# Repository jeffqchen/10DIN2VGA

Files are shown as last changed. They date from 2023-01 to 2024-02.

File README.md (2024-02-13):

# 10DIN2VGA Multi-Purpose Dongle for Sega Saturn

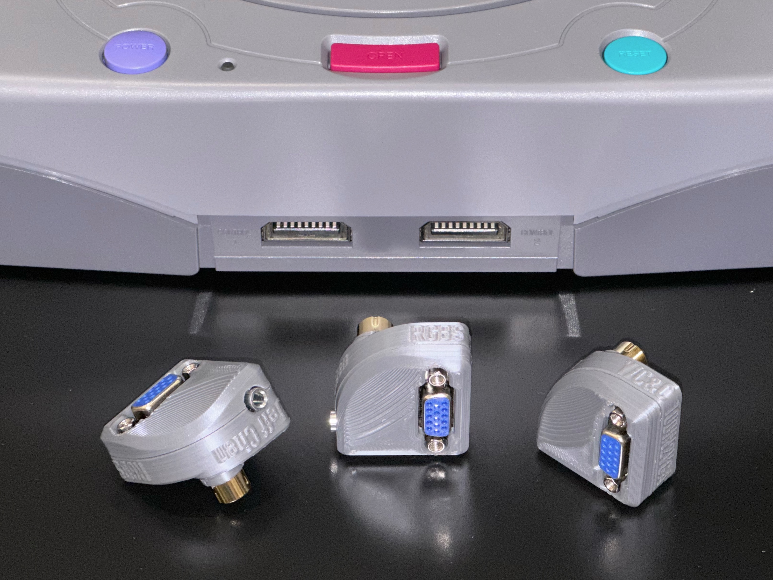
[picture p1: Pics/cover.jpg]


This is a 10-pin mini DIN to VGA dongle that supports outputting RGBS or S-video & composite video signal, plus stereo audio, from a Sega Saturn.

The RGBS signal is compatible with 75-ohm terminated SCART video.

The S-video & composite video signals are directly output from the console.

This dongle belongs to my endeavour of [Console VGA Dongles Series](https://github.com/jeffqchen/Console-VGA-Dongle-Series/blob/main/README.md).

## Functionality

You need to decide the configuration of this dongle during assembly, by closing corresponding jumpers on the PCBs.

Due to the incompatibilities between the two configurations and the possibility of causing damage by mixing up the dongle and adapter, I decided not to include switches inside the dongle, but instead solder jumpers and clear marking on the outer shell.

### RGBS Configuration

The RGBS mode is the primary objective of this project.

When configured to RGBS mode, you can opt to use C-Sync when using with an NTSC console, or use either Luma or composite video as sync for compatibility with PAL consoles.

### S-Video/Composite Video Adapter Configuration (Optional)

When configured to adapter mode, you can use the widely available and cheap VGA to S-Video/CVBS adapter from Amazon to output the aformentioned video format.

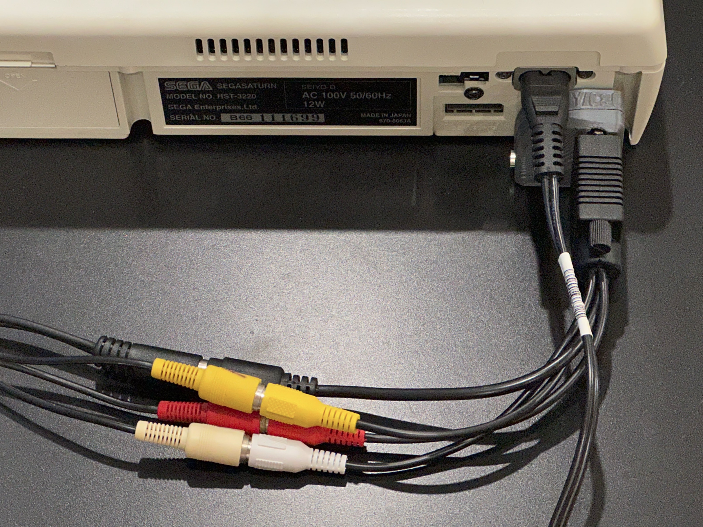
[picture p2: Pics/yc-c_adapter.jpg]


Make sure the pinout of your adapter is as the following diagram:

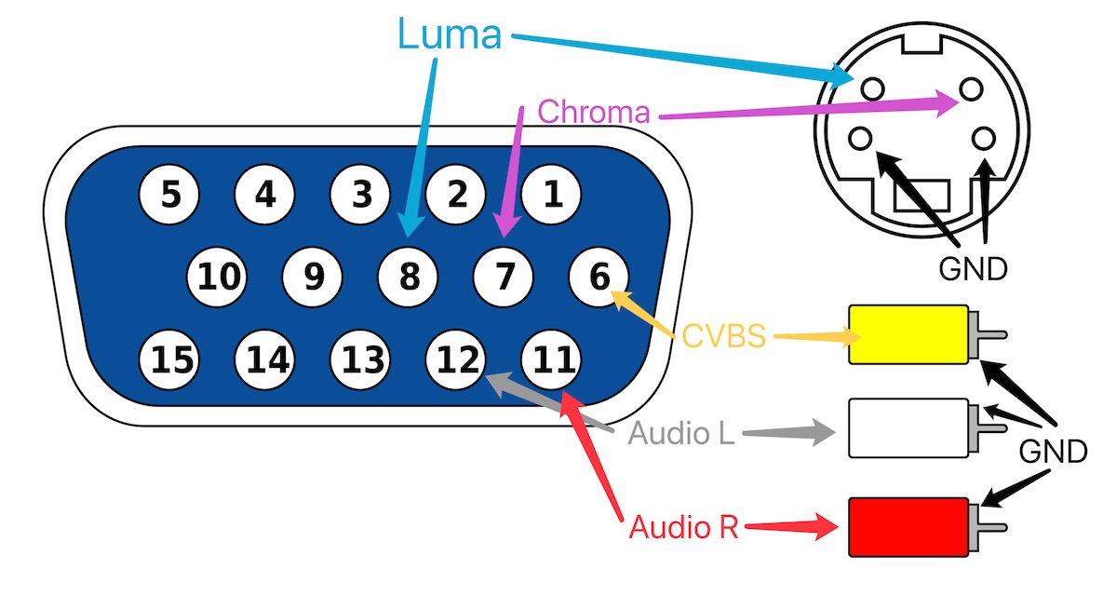
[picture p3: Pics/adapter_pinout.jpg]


*It is possible to modify the solder jumpers to change the adapter between the two configurations. However it's not recommended to repeatedly taking this dongle apart for that purpose, as the structural integrity might become compromised.*

## Design Details

The 10-pin mini DIN connector on the Sega Saturn has several problems.

The biggest one is that there is only one correct way to insert it, and infinite wrong ways to attempt. There is also no easy way to tell whether you are holding it correctly without triple checking with your eyes. It's also very difficult to maintain the correct orientation during insertion, even after you've confirmed it.

Most 10-pin DIN ports on the Saturn are badly damaged due to bad attempts to insert a video cable. Combined with too much force applied, the connector is frequently broken.

Due to the position of the port, the strain from the video cable will stress the connector and make the connection unreliable, or even reduce the life of the port and/or the cable.

The design of this dongle eliminates all the aforementioned problems.

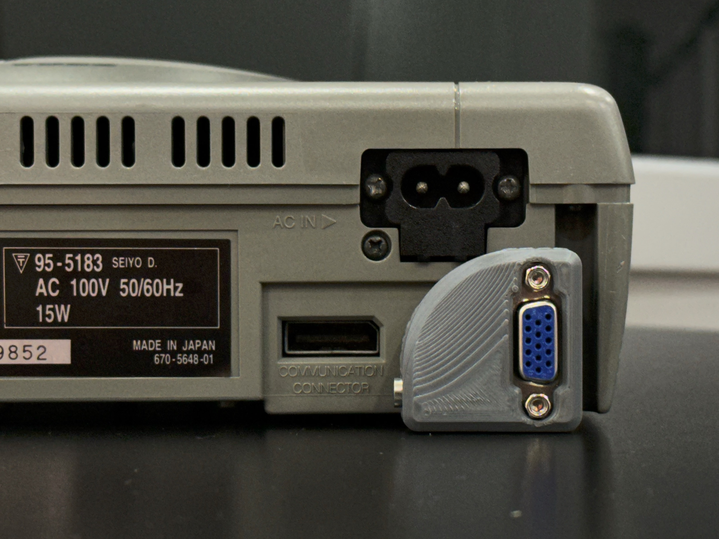
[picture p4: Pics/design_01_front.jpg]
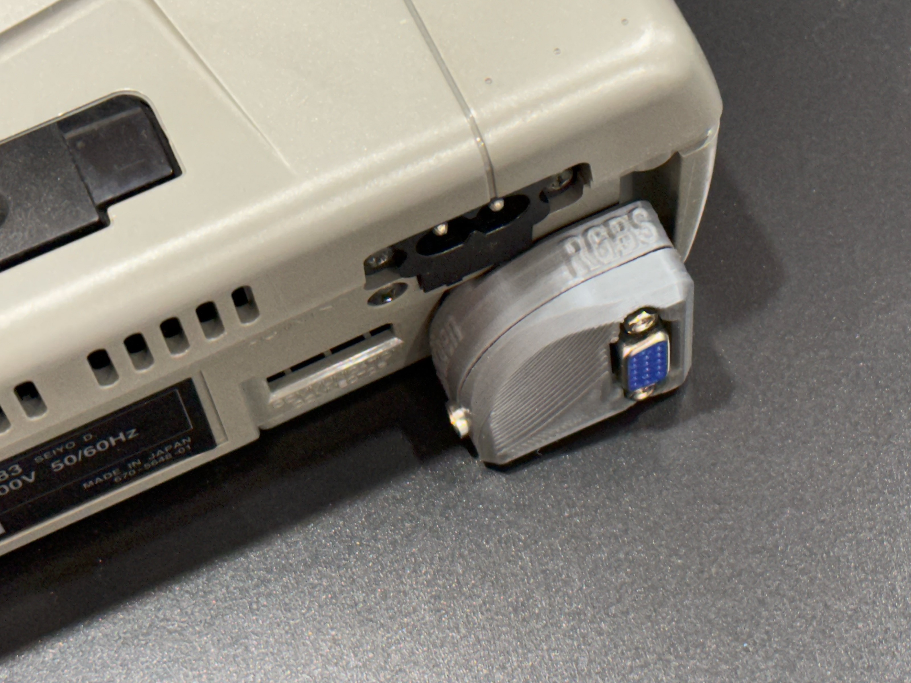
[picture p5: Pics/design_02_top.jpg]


The shape of the outside shell makes it easy to tell which way it's facing. Make sure the curve is in the 2nd quadrant and you know it's the correct way.

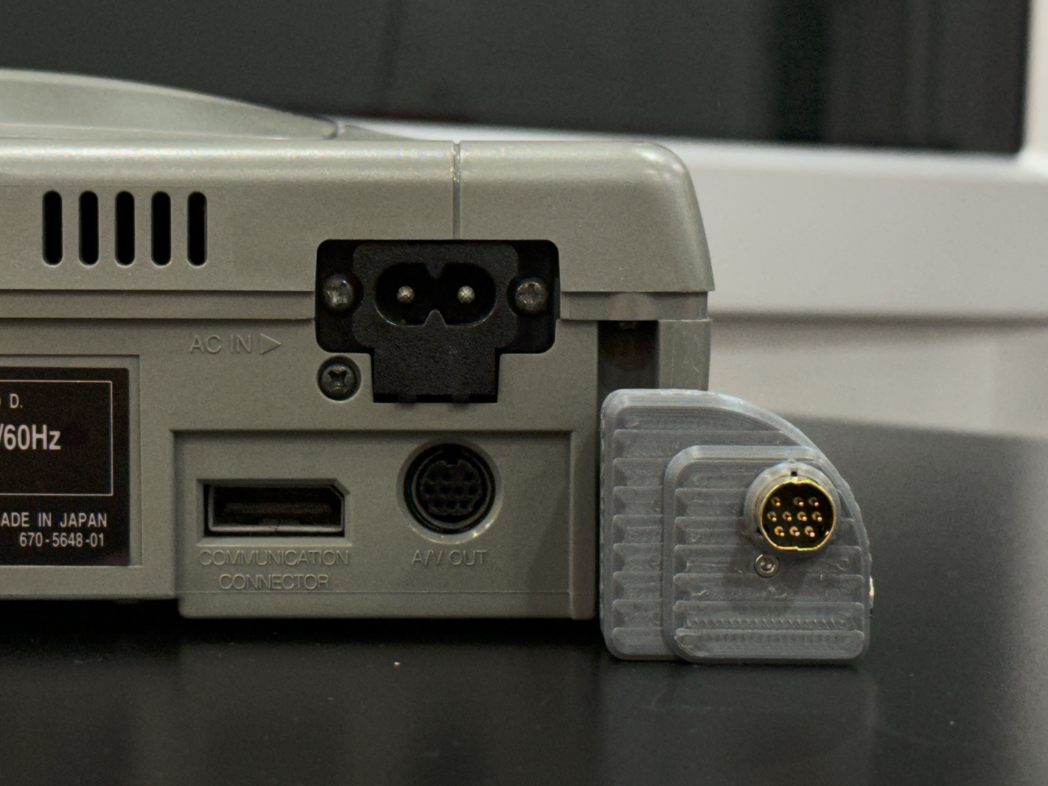
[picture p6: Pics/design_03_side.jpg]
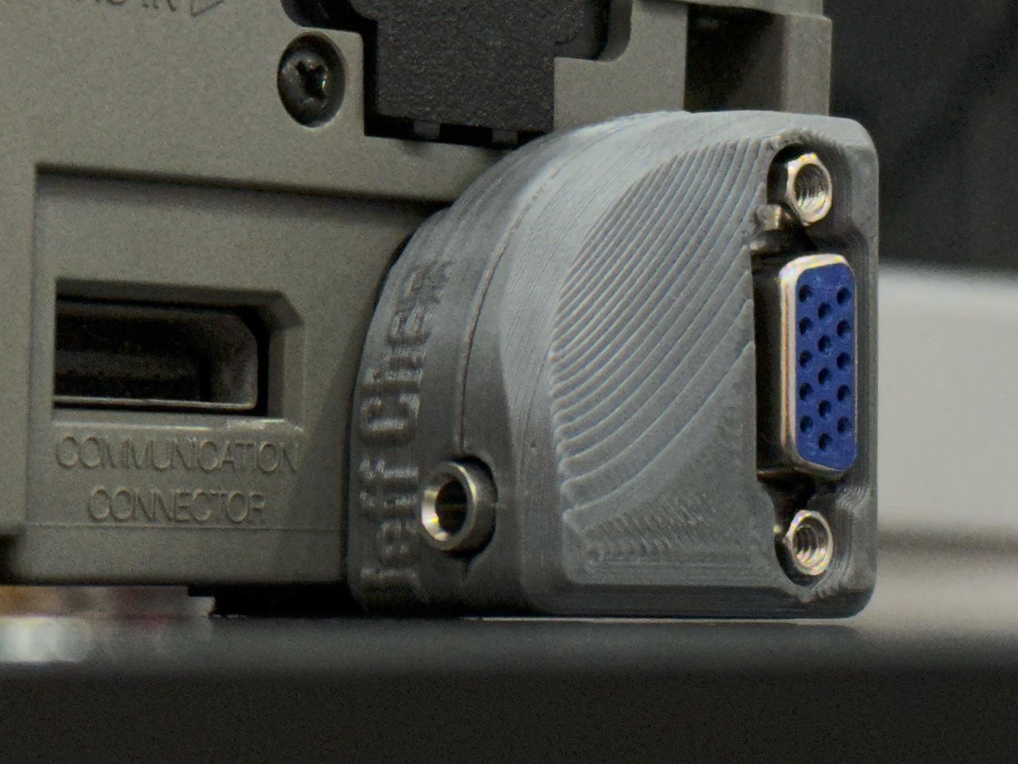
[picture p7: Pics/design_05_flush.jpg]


The shape of the inside shell conforms to the indented area around the AV port on the console, with the bottom of the dongle flat and flush with the table. This will ensure there is only one way to plug in the adapter. Since the adapter tightly follows the outline of the shell, rotational stress and downward stress are effectively offloaded to the shell of the console, as well as making it impossible to insert the connector too far into the console.

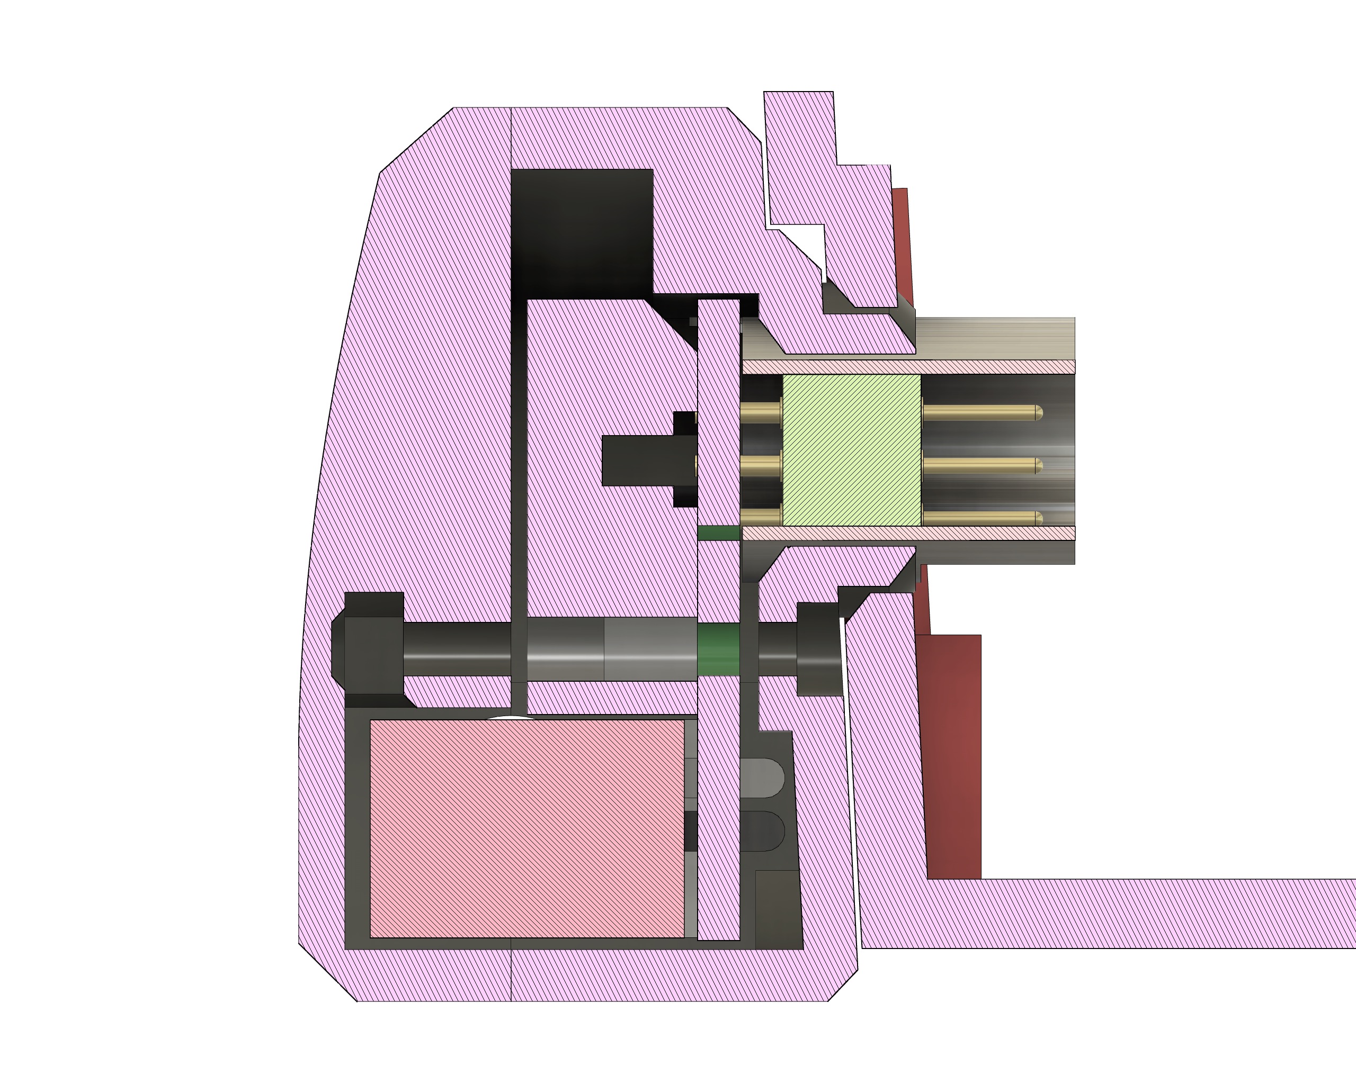
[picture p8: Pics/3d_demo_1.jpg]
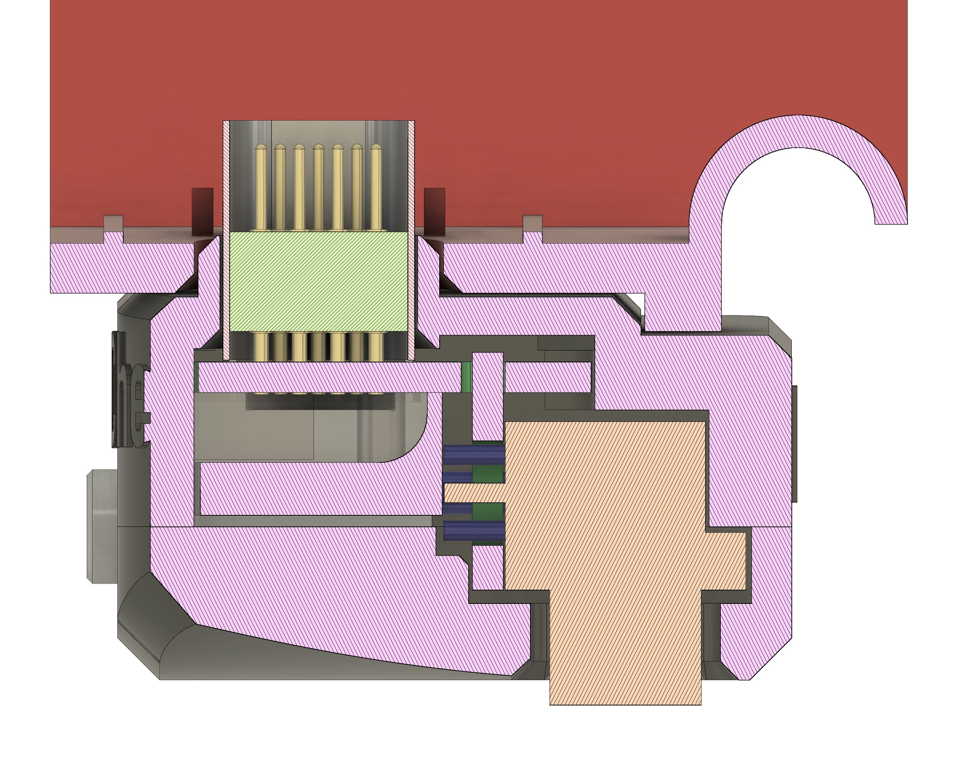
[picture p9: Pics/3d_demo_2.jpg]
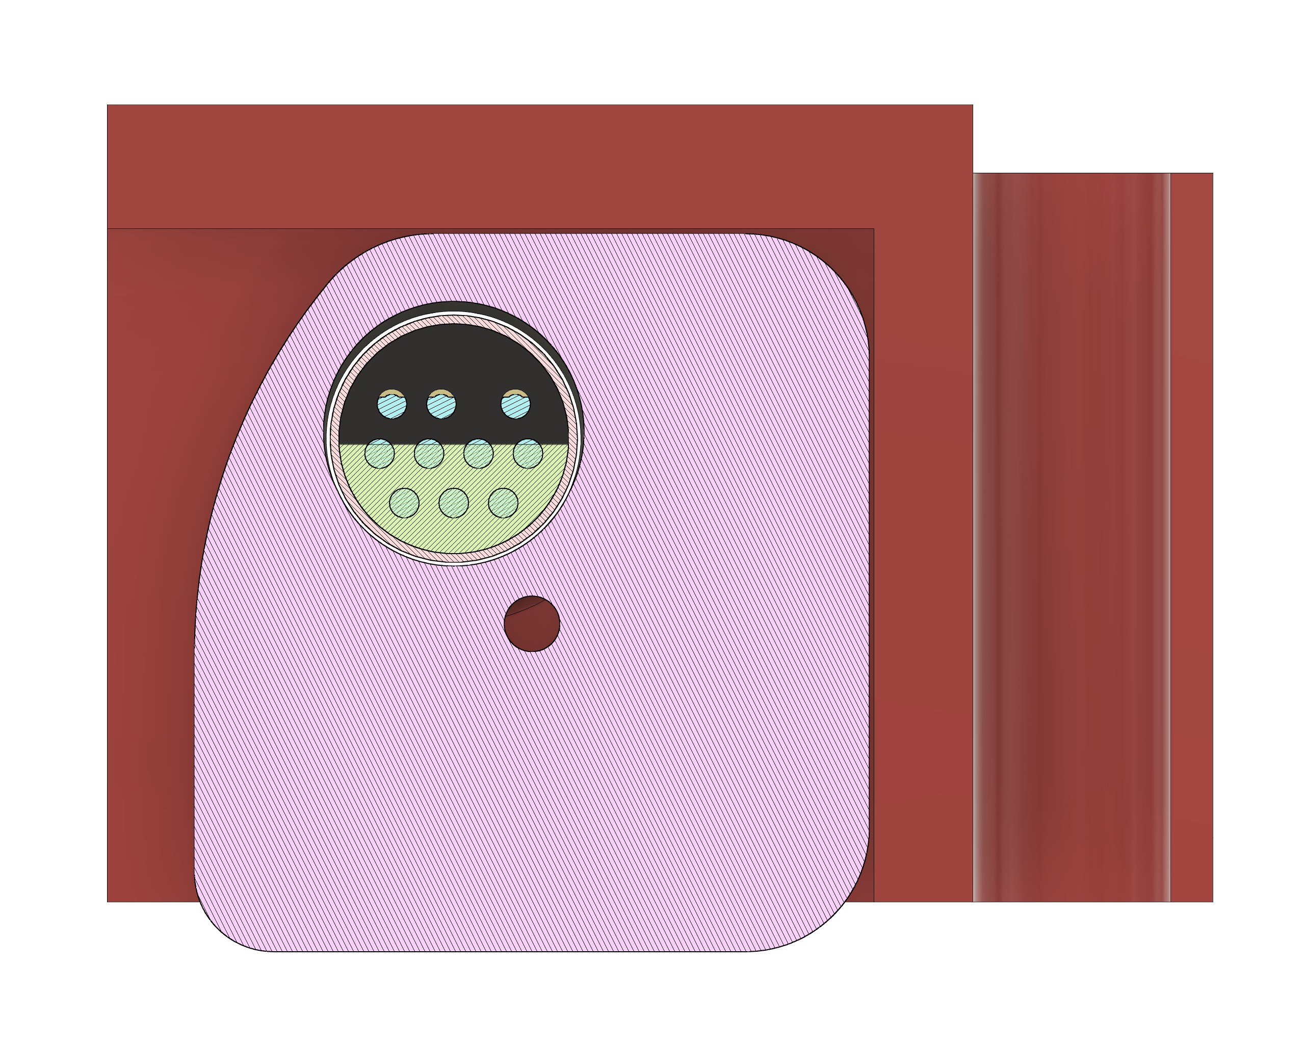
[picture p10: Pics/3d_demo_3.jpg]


The VGA port stands vertically, which ensures that it's strong against downward stress itself, as well as avoiding a rotationally pulling tendency that could pull the 10-pin DIN connector out of the console.

The optional 3.5mm audio jack was carefully positioned so that it doesn't block the communication port.

The power jack was also avoided, including the launch version with a slightly protruding profile.

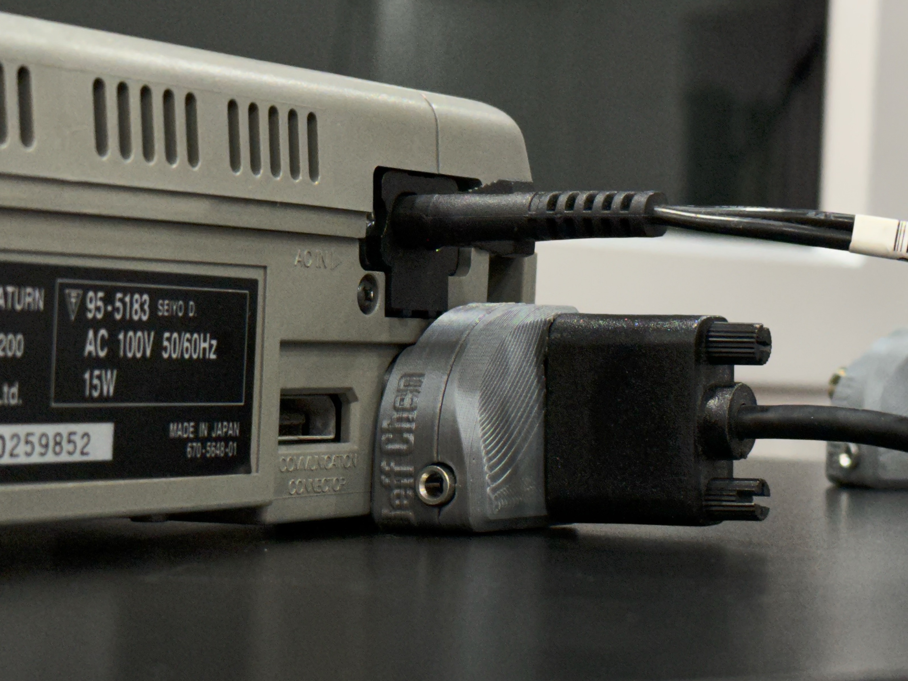
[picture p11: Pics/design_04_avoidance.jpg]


## Parts

- Project PCB
  - [Main Board](https://oshpark.com/projects/ftX4cA6v)
  - [VGA Board](https://oshpark.com/projects/xInxeNXi)
  
- 3D Printed Shell
  - [Front Shell (Universal)](https://github.com/jeffqchen/10DIN2VGA/blob/main/3D%20Print/Shell%20Front.stl)
  - Back Shell (Choose one according to your configuration)
    - [RGBS Marking](https://github.com/jeffqchen/10DIN2VGA/blob/main/3D%20Print/Shell%20Back-RGB.stl)
    - [Y/C & C Marking](https://github.com/jeffqchen/10DIN2VGA/blob/main/3D%20Print/Shell%20Back-YC.stl)
    - [No Marking](https://github.com/jeffqchen/10DIN2VGA/blob/main/3D%20Print/Shell%20Back.stl)
  - [Insert](https://github.com/jeffqchen/10DIN2VGA/blob/main/3D%20Print/Insert.stl)

- VGA Port Slim, Female - [Link](https://github.com/jeffqchen/JeffParts/blob/main/Connectors/HD15/Slim/Female%20PCB/info.md)

- 10 pin Mini DIN Male Plug, Through-Hole Type - [Link](https://github.com/jeffqchen/JeffParts/blob/main/Connectors/Mini%20DIN/10Pin/Through%20Hole/info.md)

- 3.5mm Headphone Jack, Vertical - [Link](https://github.com/jeffqchen/JeffParts/blob/main/Connectors/3.5mm%20Audio%20Jack/Vertical%205-Pin%20PCB/info.md)

- [2x] SMD Capacitor, 10uF / 6.3V / Imperial 0603 Size

- M2-16mm screw and hex nut - [Link](https://github.com/jeffqchen/JeffParts/blob/main/Parts/M2%20M3%20Hex%20Screw%20%26%20Nut/info.md)

### Optional

For CSync configuration on NTSC console
- SMD Capacitor, 220uF / 6.3V / Imperial 1206 Size - [Link](https://github.com/jeffqchen/JeffParts/blob/main/Components/220uF%20SMD%20Cap/info.md)

- SMD Resistor, 470 Ohm / Imperial 0603 Size

## 3D Printing

Print the parts in the orientation shown below. Support is required and must be completely removed after wards.

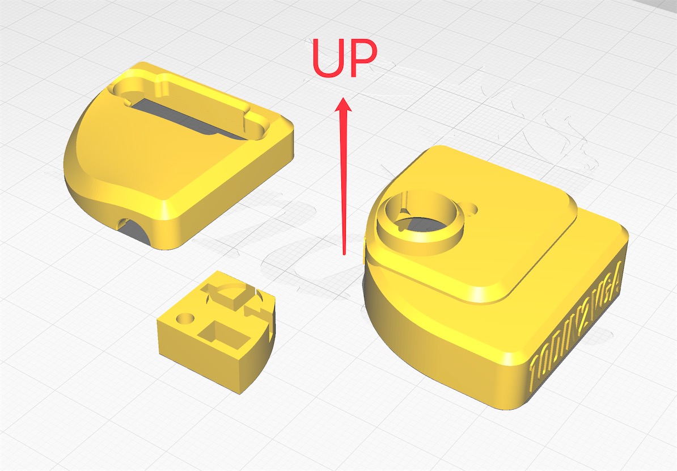
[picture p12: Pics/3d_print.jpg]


### Preparing After Printing

#### Front Shell

There will be a small piece of support material stuck inside the cavity designed for a hidden nut.

You must extract that piece of support material in order for the nut to go in.

A dental pick will work nicely. A pair of tweezers with sharp tips might work as well.

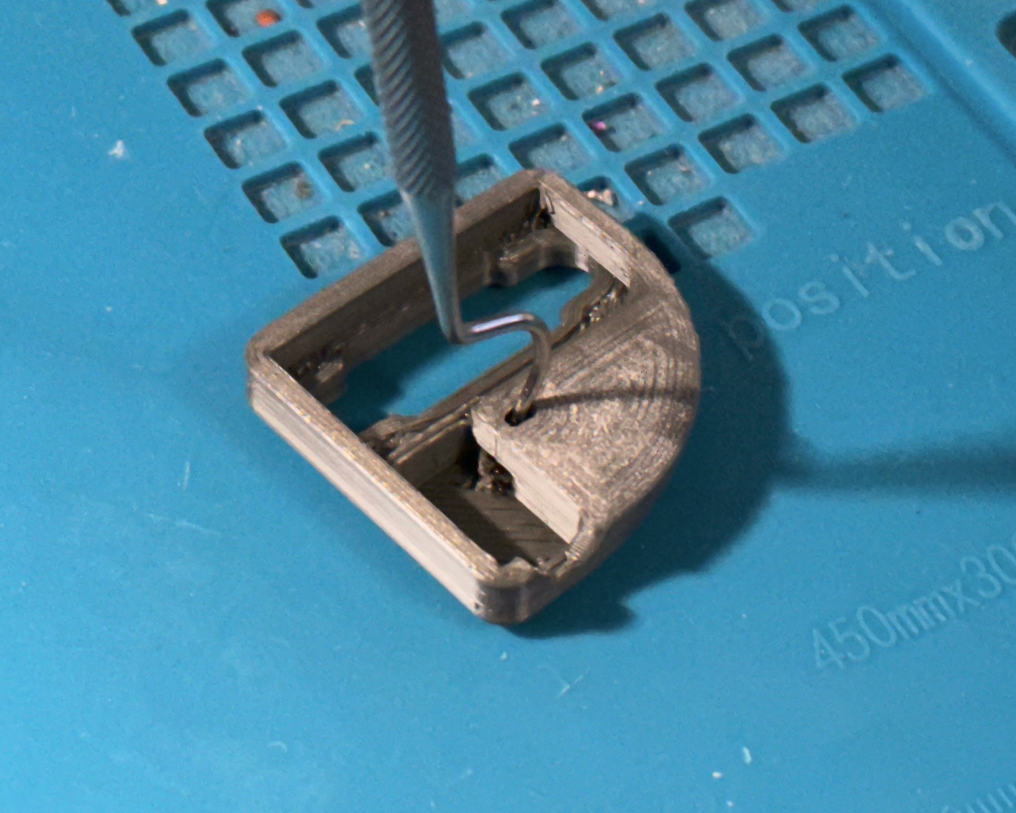
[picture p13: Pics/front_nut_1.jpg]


After extracting ALL the support material (check with a flashlight), press and fit the M2 nut inside. It might be a tight fit.

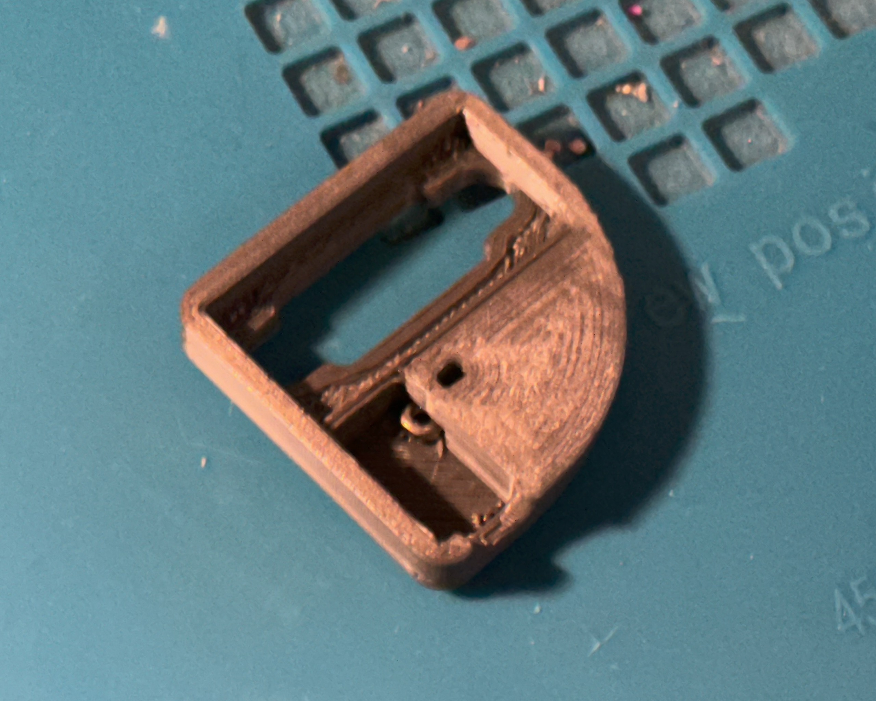
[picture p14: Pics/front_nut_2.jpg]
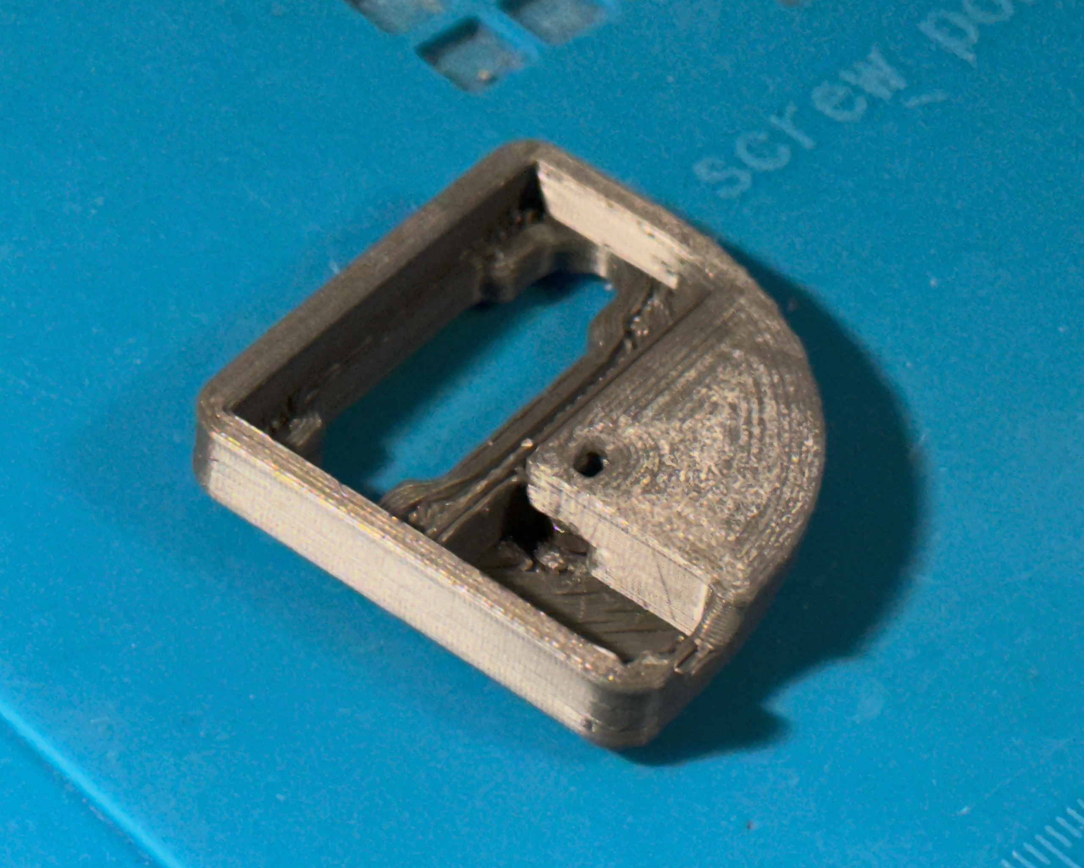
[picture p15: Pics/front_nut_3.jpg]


#### Back Shell

Make sure the barrel cavity for the 10-pin DIN connector is smooth. If you see any artifact or blob sticking into the hole, trim with a sharp knife.

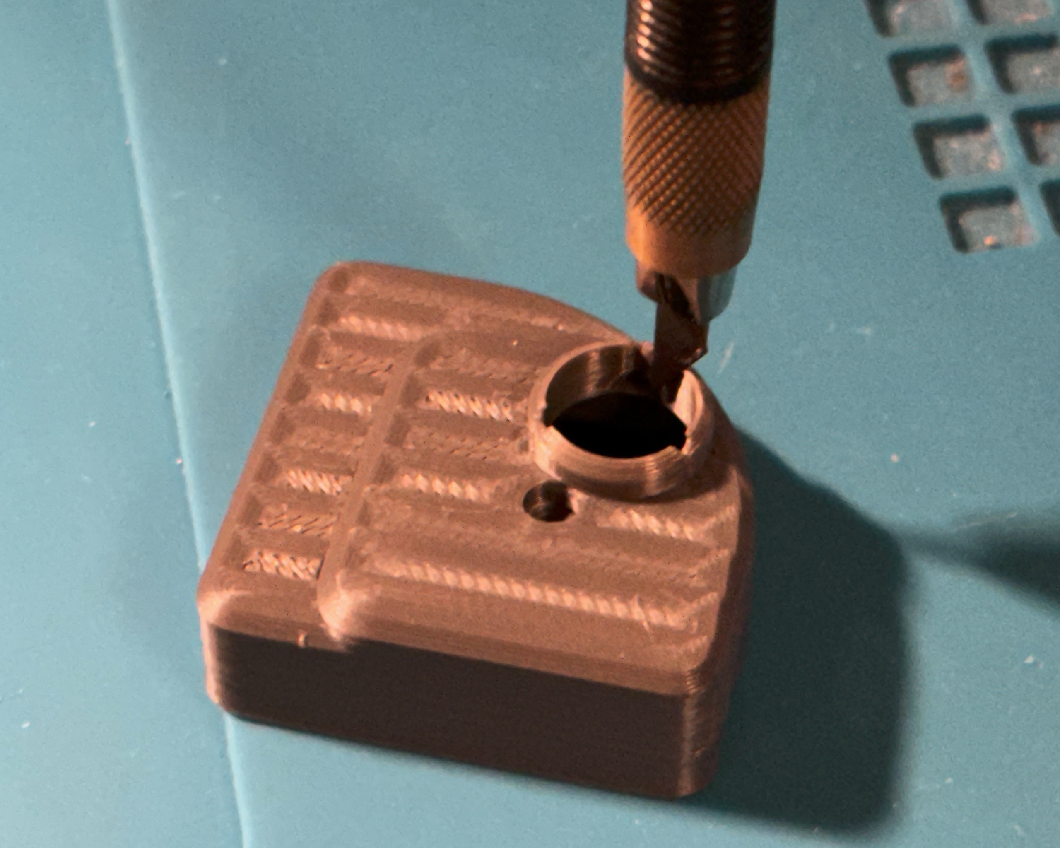
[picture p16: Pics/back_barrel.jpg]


## Assembly

### Preparing the PCB

Trim all the stubs sticking out side the PCB profile. Side cutters and files are your friends.

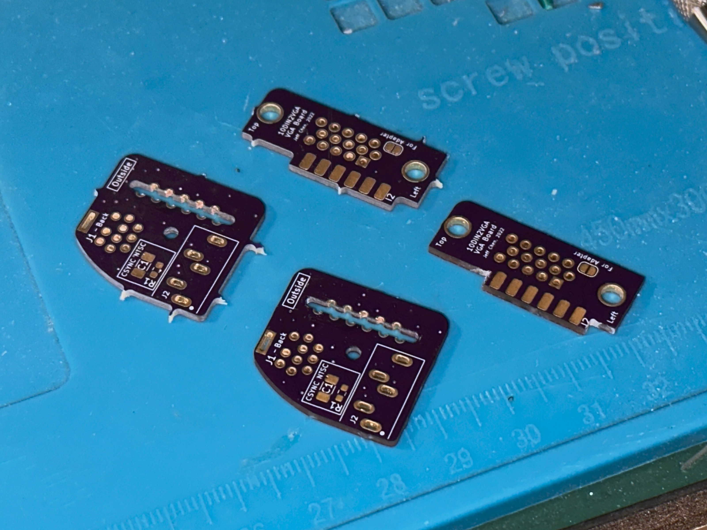
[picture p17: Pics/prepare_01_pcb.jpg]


### Combine the Two PCBs

The Two PCBs must be combined in a perfect perpendicular shape. With the help of the 3D printed insert piece, you can easily get this done.

Start by inserting the VGA board all the way into the slot in the main board. There should be NO gap.

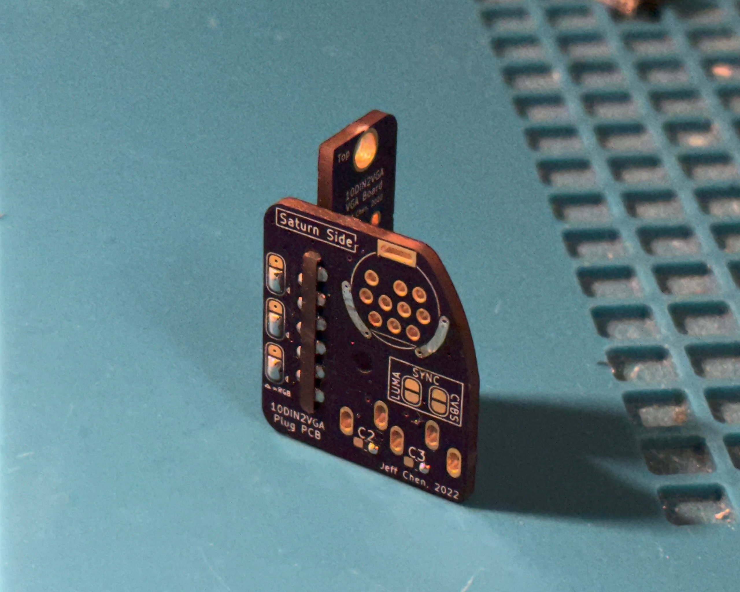
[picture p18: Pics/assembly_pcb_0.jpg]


Insert the combined PCBs into the slot in the printed insert piece.

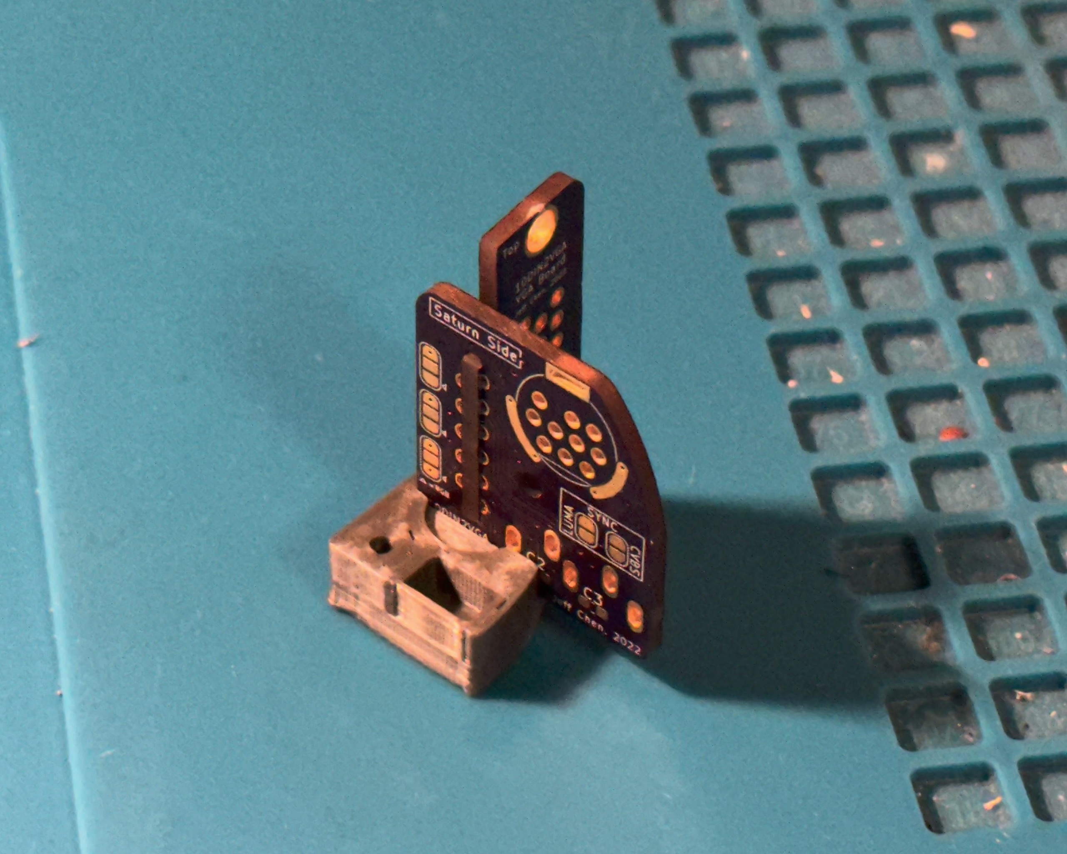
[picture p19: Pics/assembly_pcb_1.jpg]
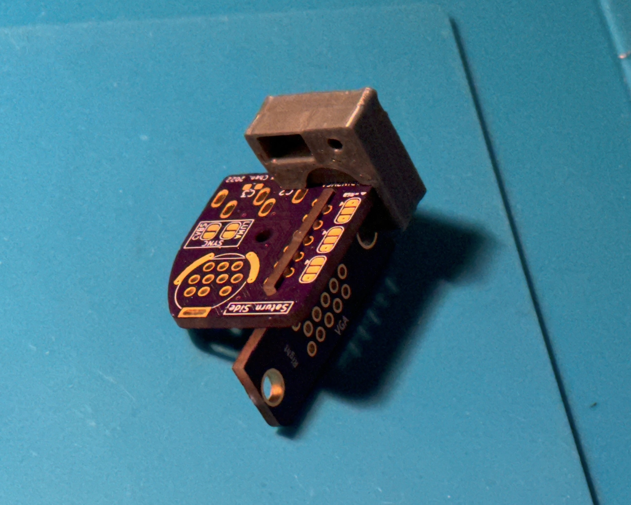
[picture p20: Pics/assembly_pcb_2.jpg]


Solder in one pin and check if the PCBs are perfectly perpendicular to each other and have no gap between each other. Adjust by re-melting the joint.

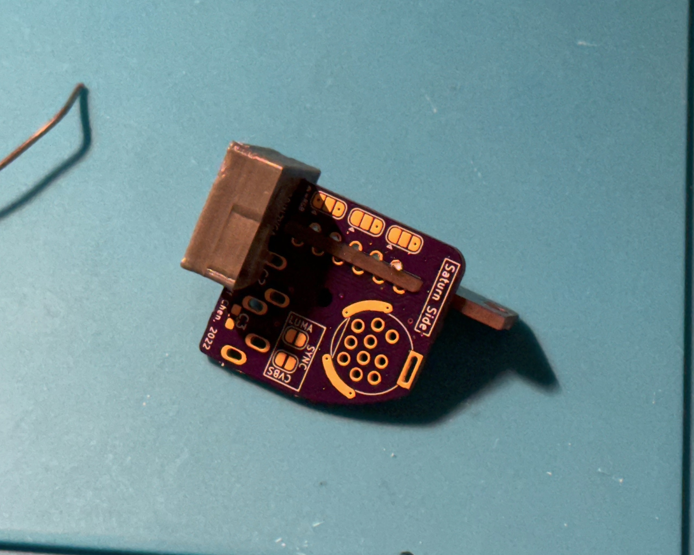
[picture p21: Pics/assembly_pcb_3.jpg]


After confirming, remove the insert and solder in the castellated vias, one side at a time.

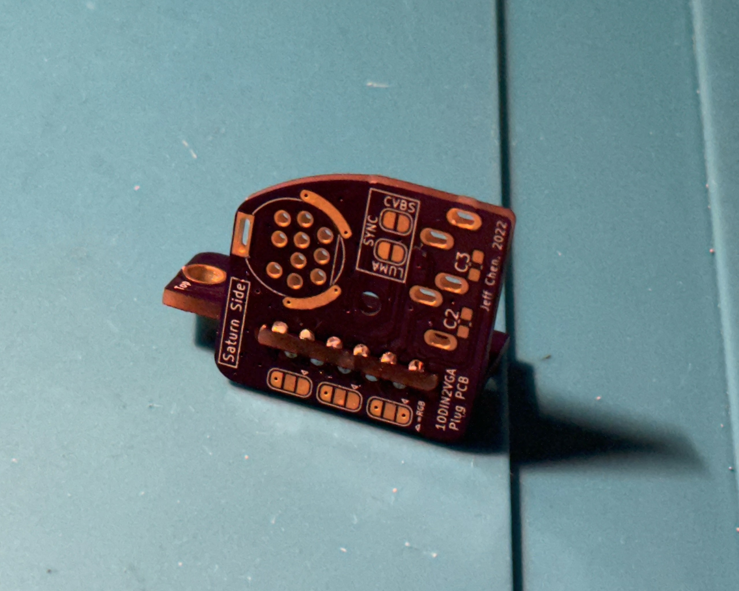
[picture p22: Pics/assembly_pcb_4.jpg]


Add ample amount of solder and make sure all the joints are nice and full.

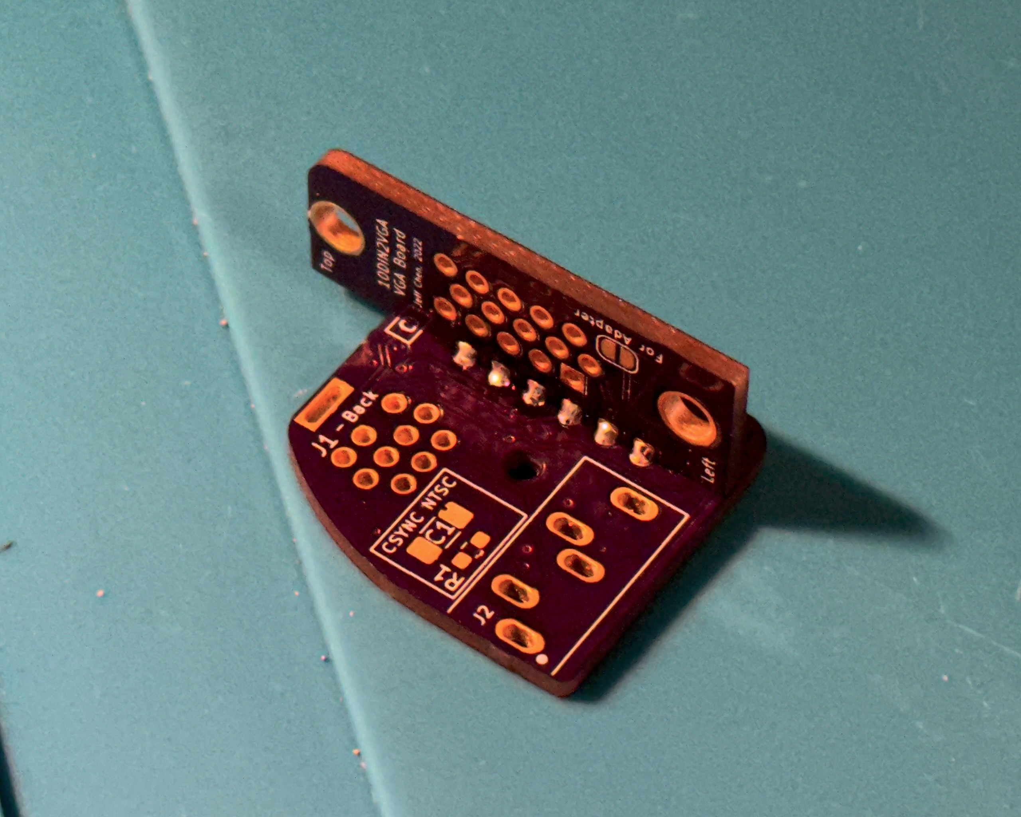
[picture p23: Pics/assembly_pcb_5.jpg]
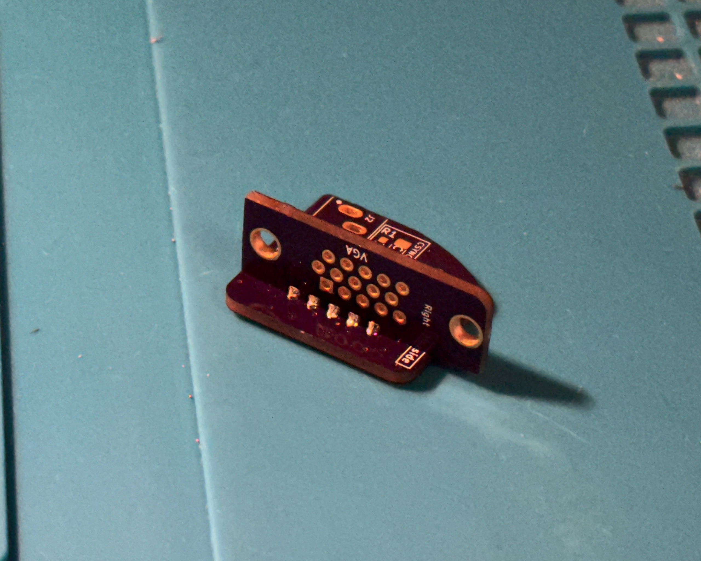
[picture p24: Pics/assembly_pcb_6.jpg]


### Solder SMD Components

Tin SMD pads for the capacitors and resistors, and solder them in place.

**If you are planning to NOT use CSync, or if your console is PAL, do NOT populate the two components inside the "CSYNC NTSC" area.**

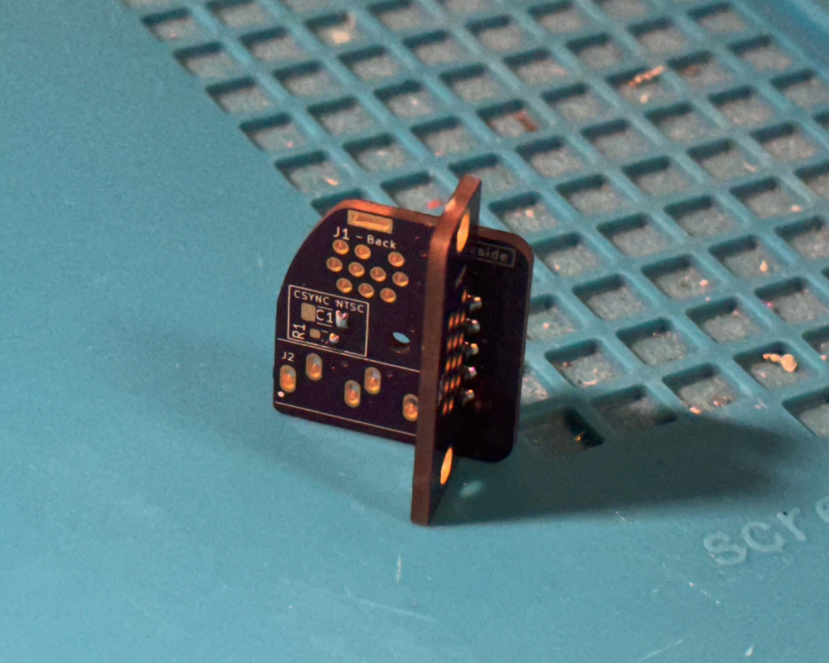
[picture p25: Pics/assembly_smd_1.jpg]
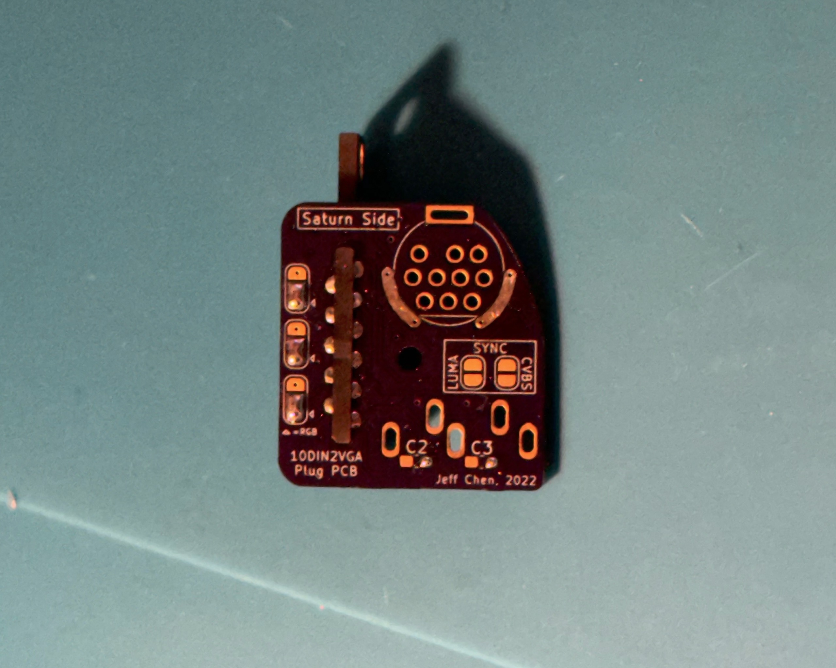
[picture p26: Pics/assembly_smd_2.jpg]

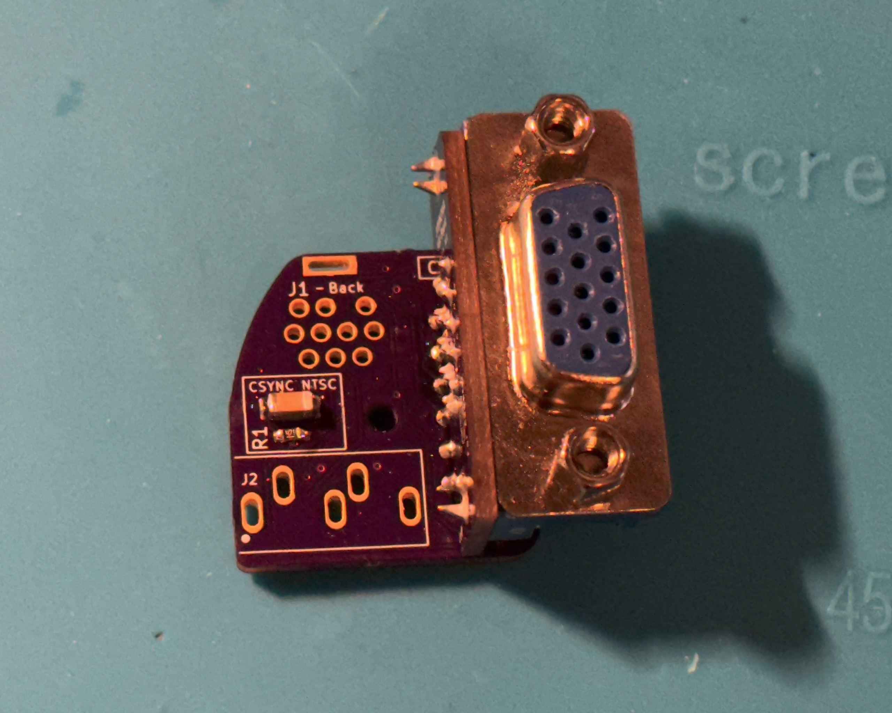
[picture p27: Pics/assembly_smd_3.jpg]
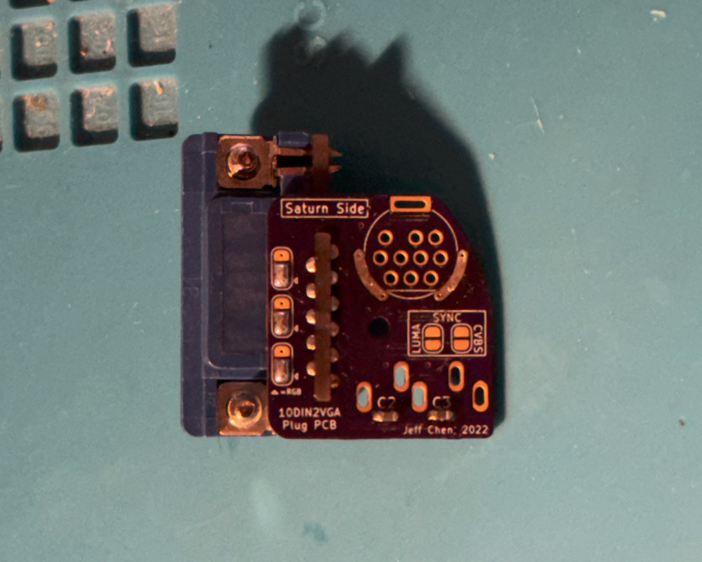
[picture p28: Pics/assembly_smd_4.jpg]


### Solder VGA Port

Nothing Special, just make sure it's all the way flush to the VGA board.



### Solder 10-pin Mini DIN Port

Pre-tin the two curvy ground pads around the 10DIN footprint on the "Saturn Side" of the main board with a small amount of solder, then wick them clean. Make sure the pads are as flat as possbile.



Insert the 10DIN port **all the way** into the PCB from the "Saturn Side" of the main board. Make sure there is no gap between the 10DIN connector and the main board.

Solder down the tongue on the top of the DIN with some solder, so the connector stays in place.

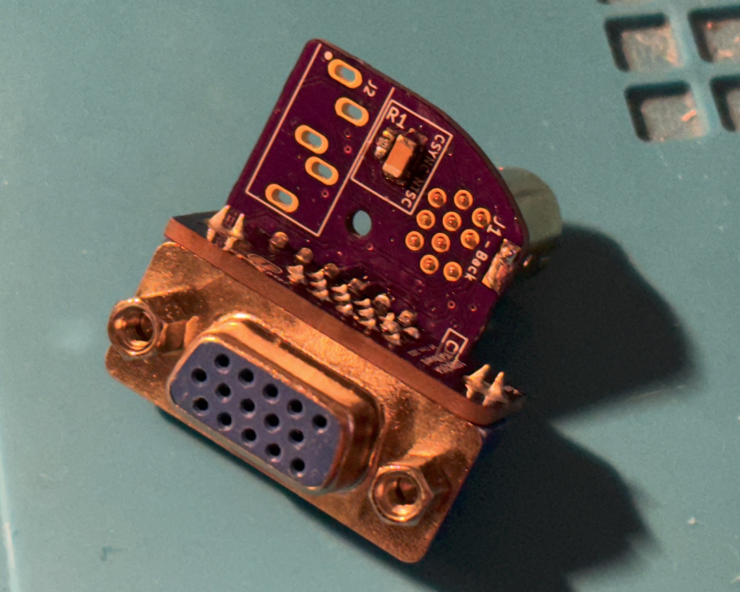
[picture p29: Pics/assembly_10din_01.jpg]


Add some solder to the curvy ground pads around the 10DIN. Make sure the solder is well-wetted to both the pads and the metal shielding.

*You might have to raise the temperature of your iron by a few dozens of degrees in Celsius if you usually solder at a lower temperature. I went from 370 to 400.*

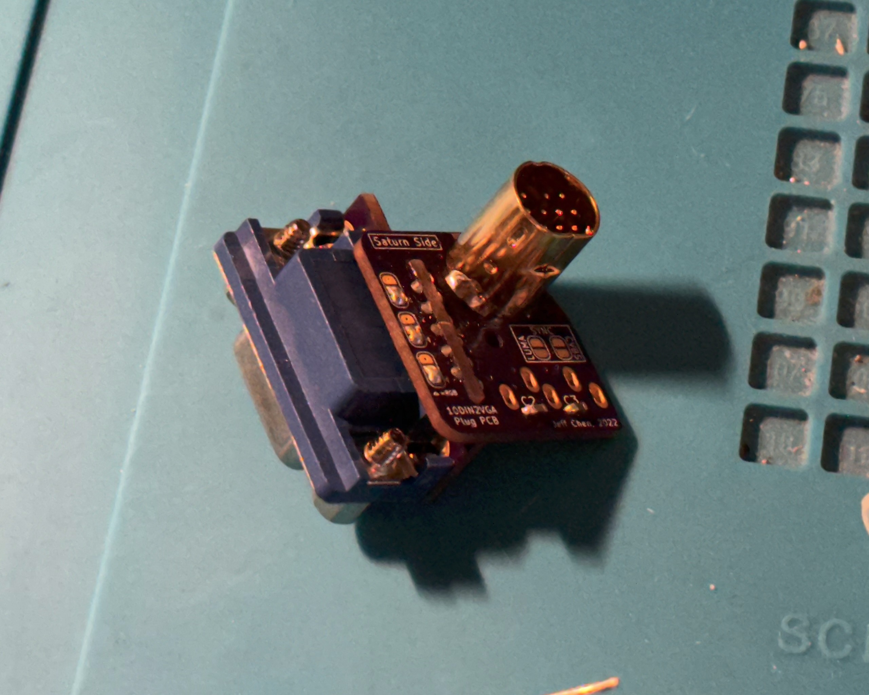
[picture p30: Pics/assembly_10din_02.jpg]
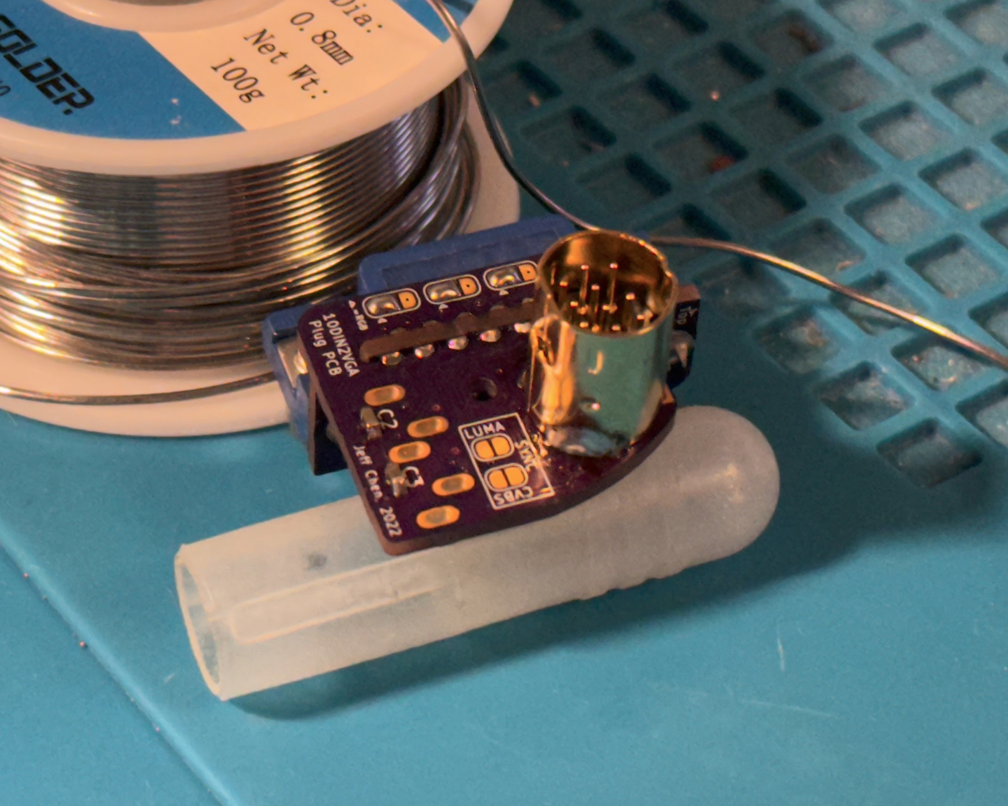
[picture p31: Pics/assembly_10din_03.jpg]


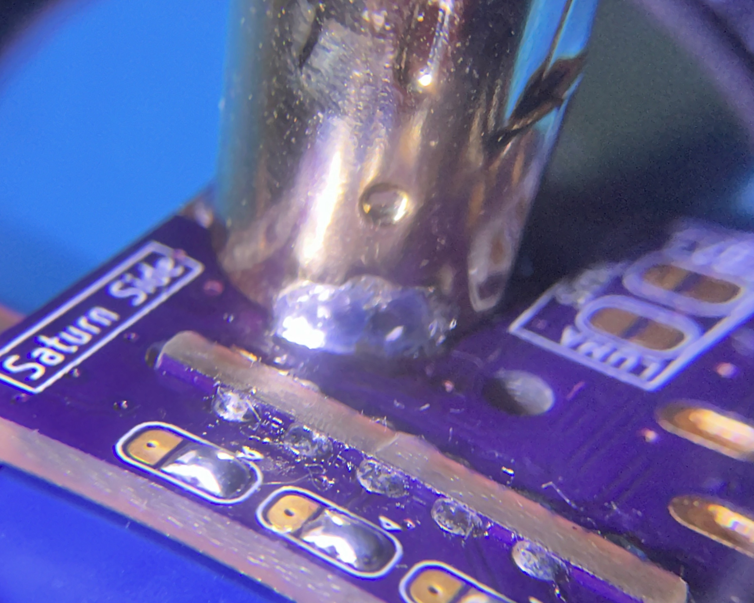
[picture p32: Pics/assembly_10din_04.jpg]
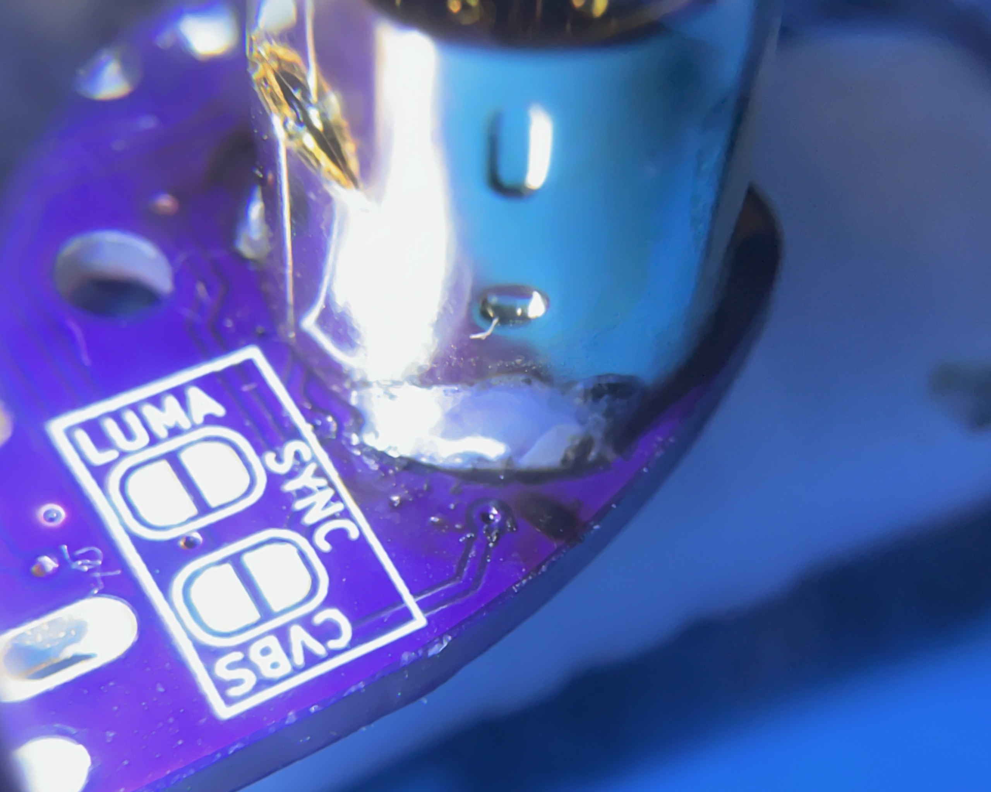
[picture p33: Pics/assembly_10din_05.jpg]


Solder in all the pins on the other side.

**Do NOT heat up these pins for too long or you risk melting plastic holding the pins inside the connector and destroying it.**

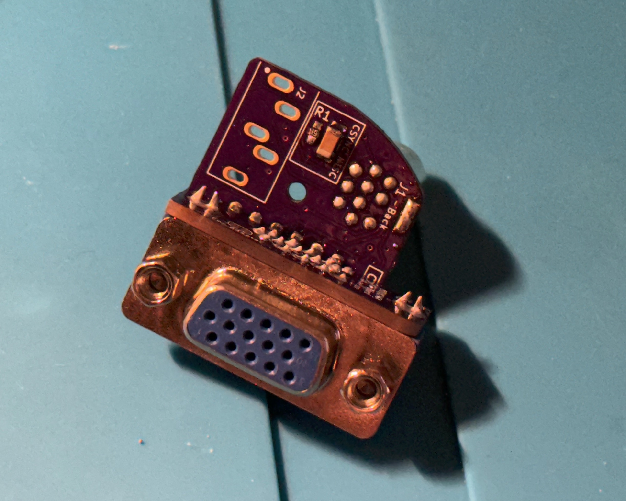
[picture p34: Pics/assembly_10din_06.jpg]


Add more solder to the top tongue and make sure solder creeps over to the other side of the PCB to form a strong joint by keeping the heat on for a bit longer.

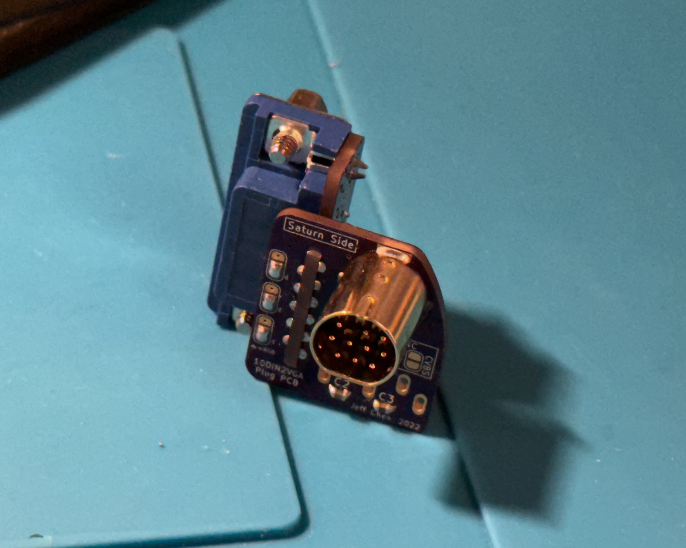
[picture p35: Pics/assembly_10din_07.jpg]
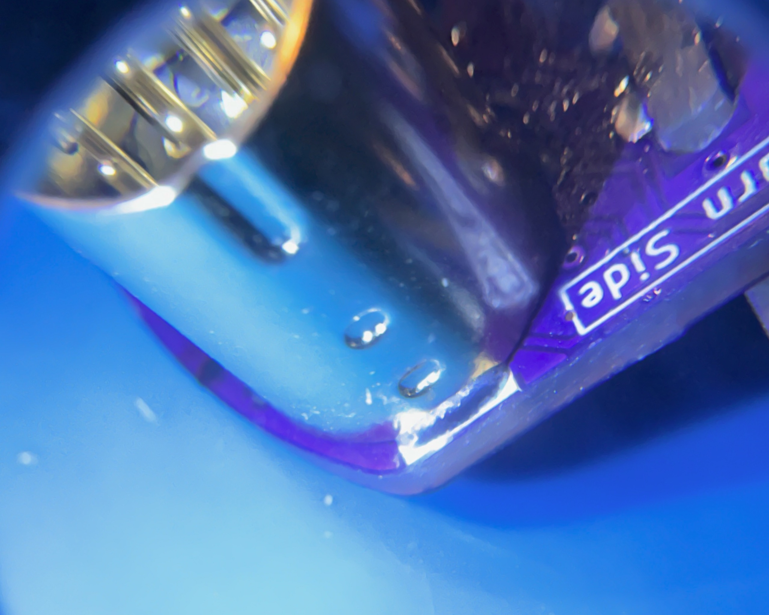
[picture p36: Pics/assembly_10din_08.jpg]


### Configure The Jumpers

#### RGBS Mode

Close the jumpers to the lower position (with triangle) on the main board. Do NOT close the jumper on the VGA board.

If you wish to use alternative sync signals (Luma OR CVBS), close the corresponding jumper inside the "Alt-Sync" area as well. **Do NOT close both of them.**



#### Adapter Mode
Close the jumpers to the upper position (without triangle) on the main board. Close the jumper on the VGA board.

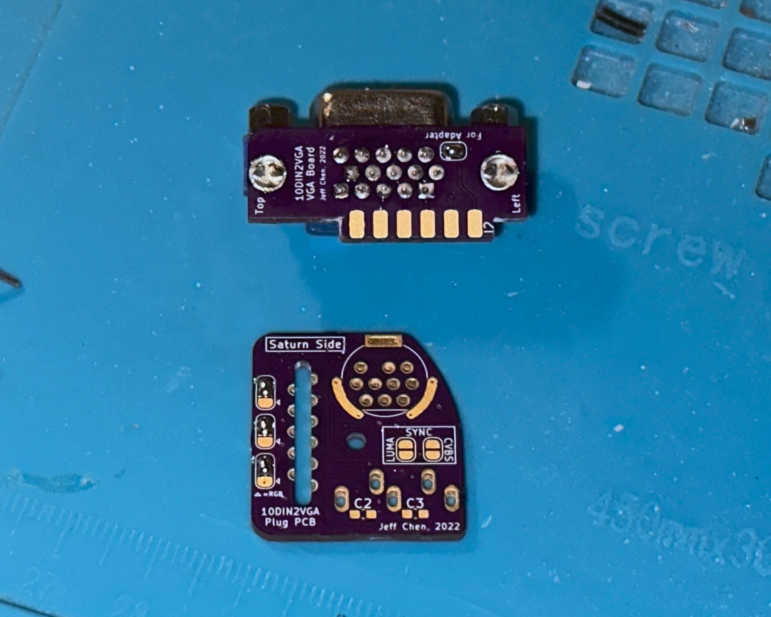
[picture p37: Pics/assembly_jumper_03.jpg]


### Solder 3.5mm Audio Jack

Insert the 3.5mm audio jack into the main PCB from the "Outside".

Make sure it's flush to the PCB, then solder in two pins with a small amount of solder.

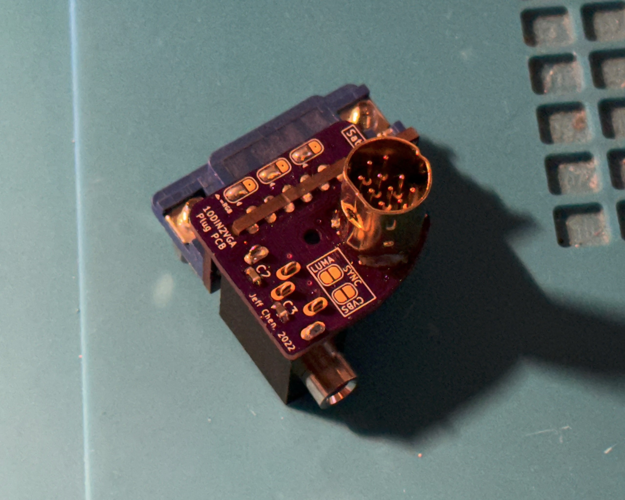
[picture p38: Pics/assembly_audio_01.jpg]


Trim all the protruding legs. Make sure they are as short as possible, but there's no need to go crazy to make it flush.

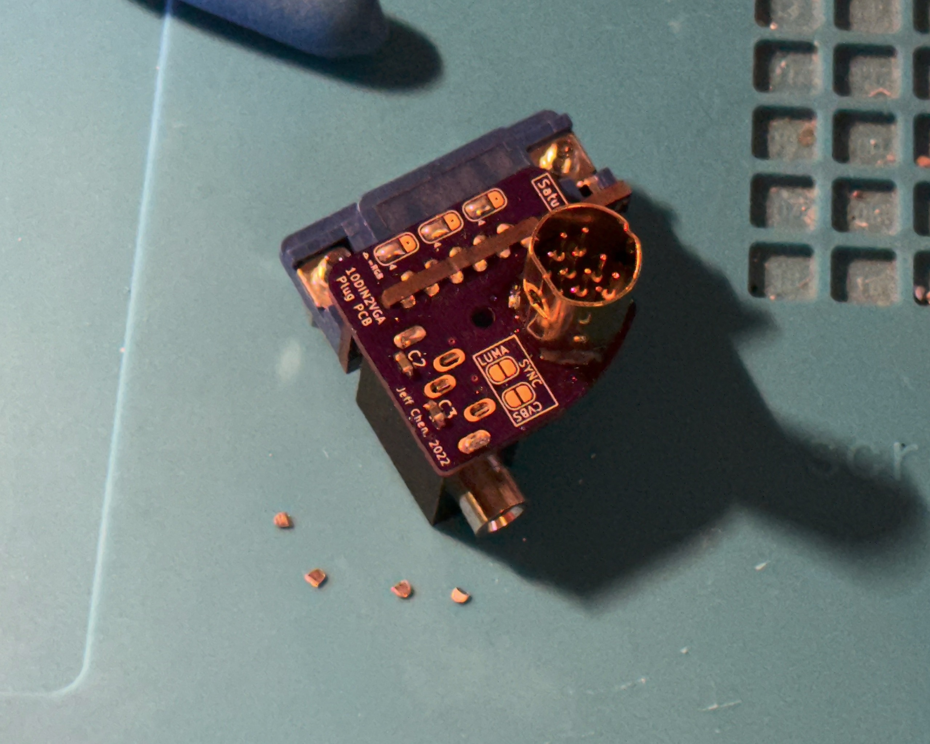
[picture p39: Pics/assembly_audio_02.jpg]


Solder in all the pins with proper amounts of solder.

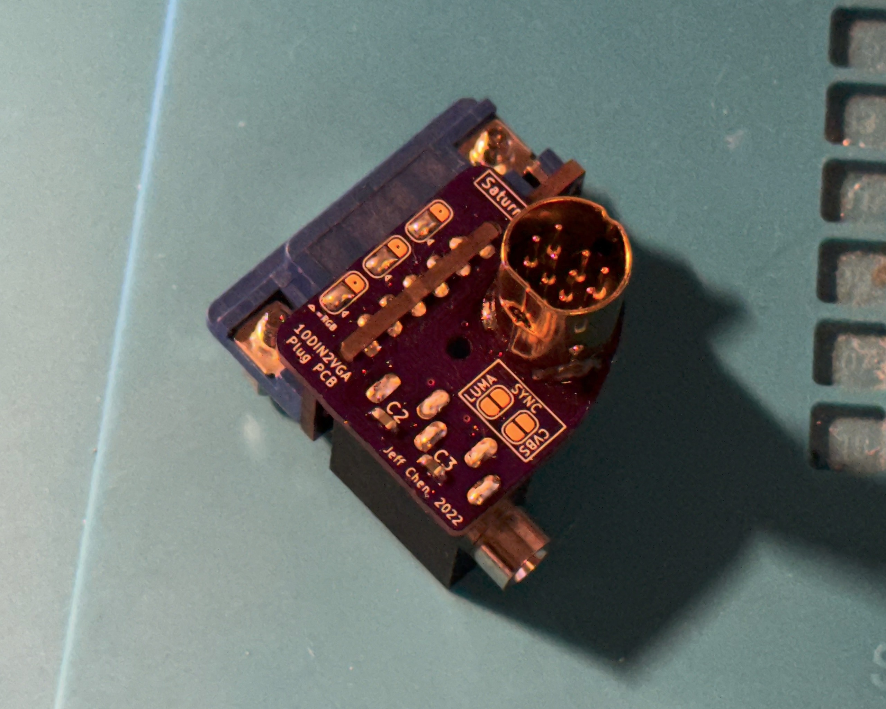
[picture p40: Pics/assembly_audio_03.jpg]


### Closing The Shell

Start by inserting the 10-pin DIN into the shell from the inside.

This will be a tight fit. Try pressing straight down from the back of the DIN connector to avoid lateral movements.



If it's difficult, use the insert piece as a thumb guard as below.

The insert piece should be left inside the shell as a support piece. It should be flush or below the shell interface. If it's sticking out, the board assembly is not in place.



Push down the PCB all the way. Use the 3.5mm jack as a reference. The port should touch the shell when the board assembly is in place.



Close the front shell onto the assembly. Hold the shells together with one hand, and put the M2-16mm screw in.

When it begins to feel harder to turn the screw driver, start using only 3 fingers to turn the screw driver in order to prevent over-tightening it and cracking the front shell.

The screw head should be flush or slightly below the back surface of the dongle as shown below.



And you have built the dongle!



#### Double Down On Strength

I've left a few gaps around the 10-pin DIN connector barrel. You may inject small amounts of super glue or even epoxy to make it indestructible. I didn't feel the necessity personally, but just in case your printer came out with a piece that's slightly loose.



#### If the 10-pin DIN Barrel Was Impossible To Push In

Your printer might give you a print with the barrel cavity being too tight. You can try using "Hole Horizontal Expansion" in Cura (or an equivalent option in other slicer software) to give it a 0.1mm expansion.

----------------
Shield: [][cc-by-nc-sa]

This work is licensed under a
[Creative Commons Attribution-NonCommercial-ShareAlike 4.0 International License][cc-by-nc-sa].

[][cc-by-nc-sa]

[cc-by-nc-sa]: http://creativecommons.org/licenses/by-nc-sa/4.0/
[cc-by-nc-sa-image]: https://licensebuttons.net/l/by-nc-sa/4.0/88x31.png
[cc-by-nc-sa-shield]: https://img.shields.io/badge/License-CC%20BY--NC--SA%204.0-lightgrey.svg

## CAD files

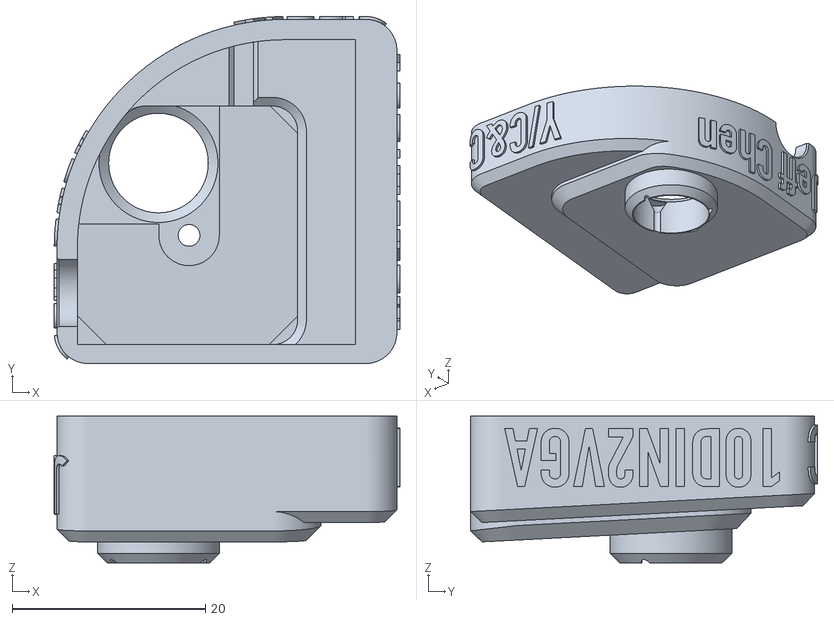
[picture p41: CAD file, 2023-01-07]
3D Print/Shell Back-YC.stl
35.8 x 35.9 x 15.2

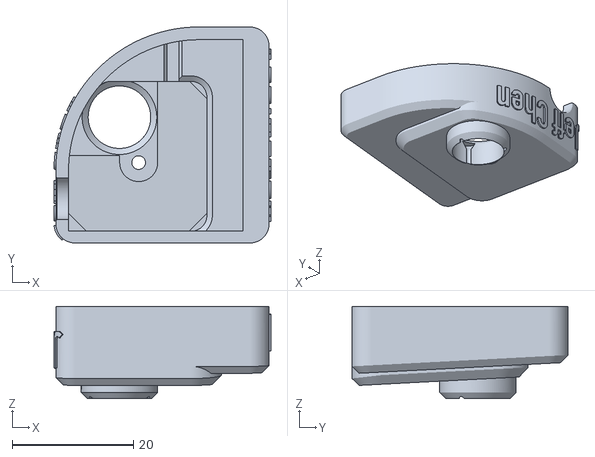
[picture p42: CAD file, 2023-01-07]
3D Print/Shell Back.stl
35.8 x 35.6 x 15.2

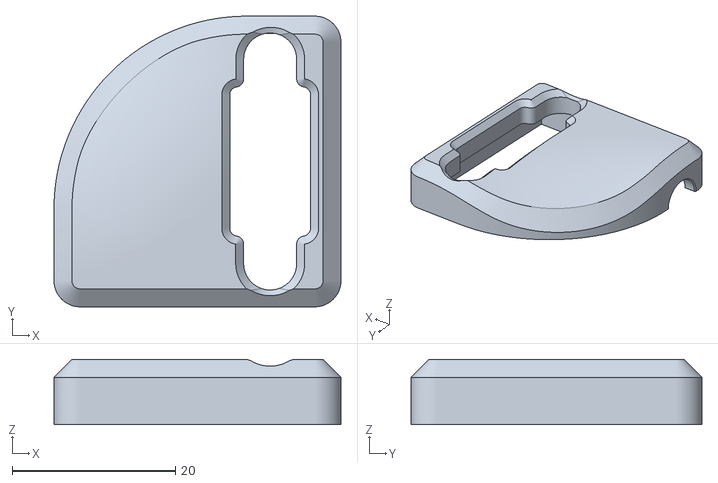
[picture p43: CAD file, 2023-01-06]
3D Print/Shell Front.stl
35.1 x 35.6 x 8.00

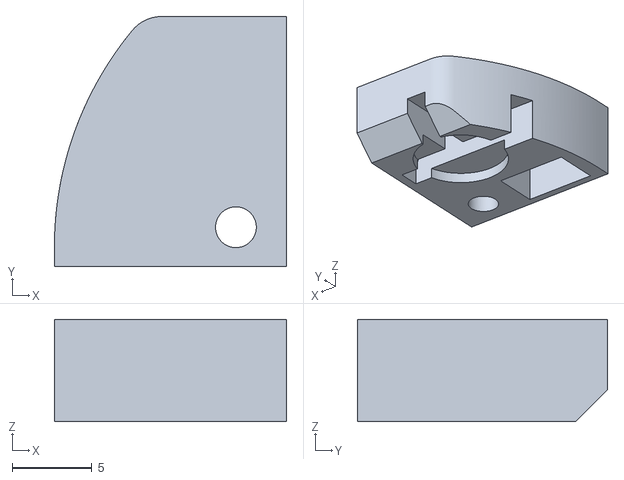
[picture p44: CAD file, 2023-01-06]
3D Print/Insert.stl
14.5 x 15.6 x 6.40

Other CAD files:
3D Print/Shell Back-RGB.stl

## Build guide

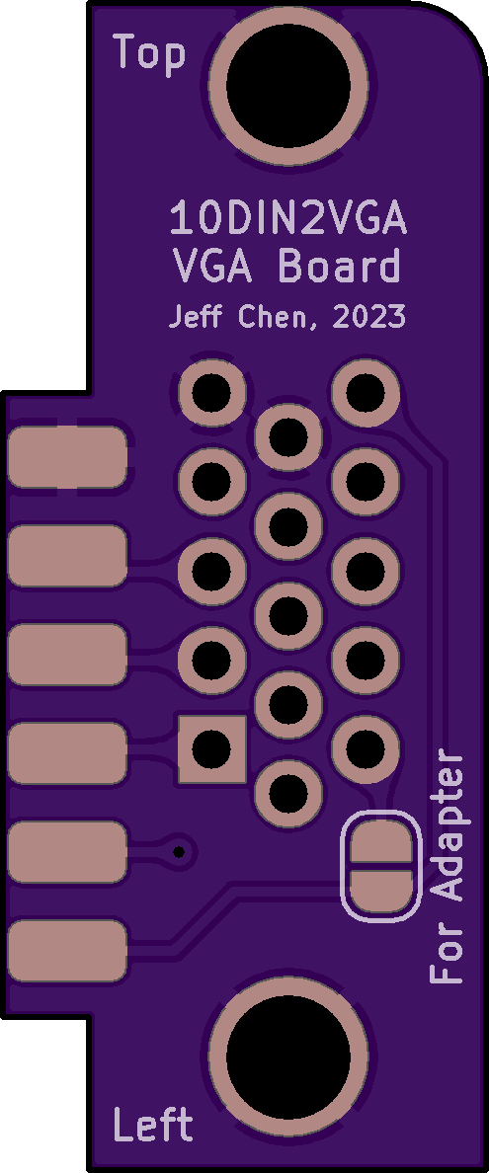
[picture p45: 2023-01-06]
Pics/assembly_jumper_02.png

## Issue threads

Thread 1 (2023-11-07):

MVX Issues

hipsofjw, 2023-11-07:
Hello!

I recently bought a couple of Extron MVX matrix switchers and so dove into making your adapters. This is the first one I've made and am having issues. When I go directly into my JVC TM-H150CG or into the Retrotink 5X through an RGB2SCART box, all is good. But I'm getting sync issues through the MVX to the JVC and no image at all through the MVX and RGB2SCART to the Retrotink 5X. I've configured the jumpers for RGBS mode and haven't closed the other ones. I also have the SMD components installed for CSYNC.

Maybe I've messed something up soldering, but I'm not seeing any issues visually or through my multimeter. If you could give me some advice, let me know!

Thanks for these projects by the way. I've had fun building them so far.

hipsofjw, 2023-11-07:
The JVC can handle TTL signals fine, but I also have a 470 to 1k resistor on the sync line from the MVX to the JVC anyway. Since neither the JVC or the 5X recognize the 10DIN2VGA sync through the MVX but do directly, I think the problem right now is that the MVX is having a problem with the sync from the 10DIN2VGA. Do you have any idea why this could happen? For science, I tried using my other MVX and had the same issue.

jeffqchen, 2023-11-07:
I just tested the one I have in hand.

Saturn to MVX to 5X. It worked without any issue. The sync resistor used inside the dongle was 470 ohm.

Please check the VGA cables you are using.

hipsofjw, 2023-11-07:
Thanks for getting back to me. VGA cables are good. New and shielded. Did a continuity check and all the pins are wired.

Must be my bad SMD soldering. I'm new to it. I'm going to start fresh with a new board tomorrow and give it whirl. Too difficult to move the little things around now that I have the big components on.

Thanks again!

Closed 2024-02-12.

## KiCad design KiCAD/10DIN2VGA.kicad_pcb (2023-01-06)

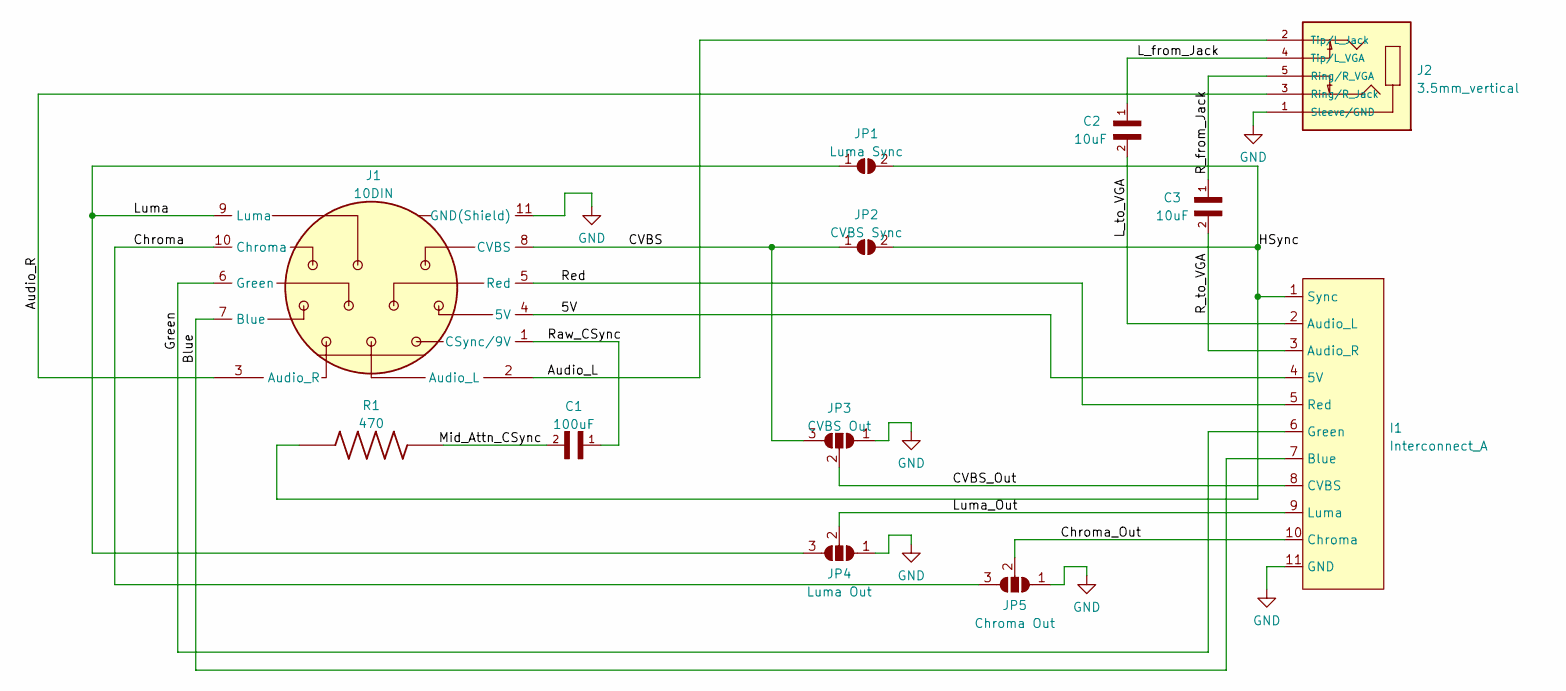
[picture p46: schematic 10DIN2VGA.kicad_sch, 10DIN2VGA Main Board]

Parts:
C1: 100uF; C_1206_3216Metric_Pad1.33x1.80mm_HandSolder
C2, C3: 10uF; C_0603_1608Metric_Pad1.08x0.95mm_HandSolder
I1: Interconnect_A
J1: 10DIN
J2: 3.5mm_vertical; PARTREV 1.01
JP1: Luma Sync; SolderJumper-2_P1.3mm_Open_RoundedPad1.0x1.5mm
JP2: CVBS Sync; SolderJumper-2_P1.3mm_Open_RoundedPad1.0x1.5mm
JP3: CVBS Out; SolderJumper-3_P1.3mm_Open_RoundedPad1.0x1.5mm
JP4: Luma Out; SolderJumper-3_P1.3mm_Open_RoundedPad1.0x1.5mm
JP5: Chroma Out; SolderJumper-3_P1.3mm_Open_RoundedPad1.0x1.5mm
R1: 470; R_0603_1608Metric_Pad0.98x0.95mm_HandSolder

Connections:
/5V: I1.4 (5V), J1.4 (5V)
/Audio_L: J1.2 (Audio_L), J2.2 (Tip/L_Jack)
/Audio_R: J1.3 (Audio_R), J2.3 (Ring/R_Jack)
/Blue: I1.7 (Blue), J1.7 (Blue)
/CVBS: J1.8 (CVBS), JP2.1 (A), JP3.3 (B)
/CVBS_Out: I1.8 (CVBS), JP3.2 (C)
/Chroma: J1.10 (Chroma), JP5.3 (B)
/Chroma_Out: I1.10 (Chroma), JP5.2 (C)
/Green: I1.6 (Green), J1.6 (Green)
/HSync: I1.1 (Sync), JP1.2 (B), JP2.2 (B), R1.1
/L_from_Jack: C2.1, J2.4 (Tip/L_VGA)
/L_to_VGA: C2.2, I1.2 (Audio_L)
/Luma: J1.9 (Luma), JP1.1 (A), JP4.3 (B)
/Luma_Out: I1.9 (Luma), JP4.2 (C)
/Mid_Attn_CSync: C1.2, R1.2
/R_from_Jack: C3.1, J2.5 (Ring/R_VGA)
/R_to_VGA: C3.2, I1.3 (Audio_R)
/Raw_CSync: C1.1, J1.1 (CSync/9V)
/Red: I1.5 (Red), J1.5 (Red)
GND: I1.11 (GND), J1.11 (GND(Shield)), J2.1 (Sleeve/GND), JP3.1 (A), JP4.1 (A), JP5.1 (A)

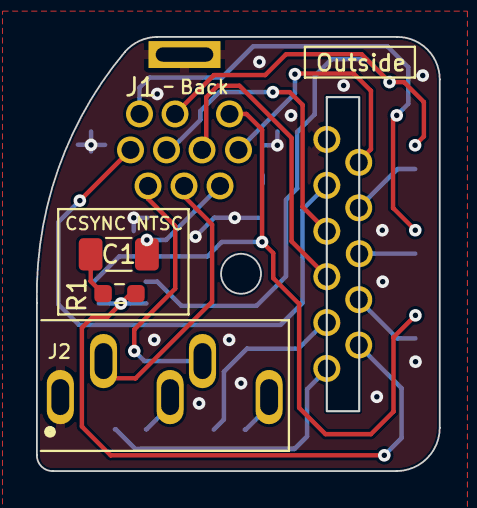
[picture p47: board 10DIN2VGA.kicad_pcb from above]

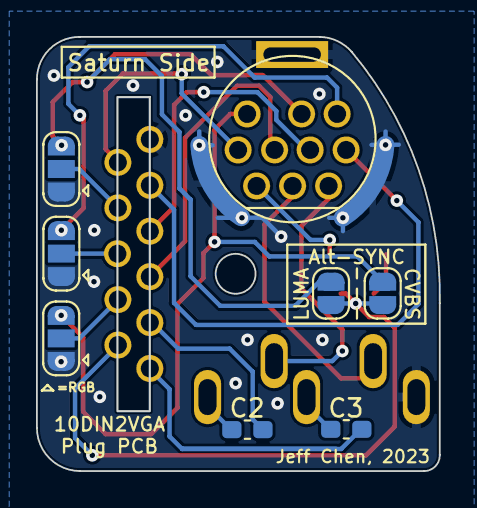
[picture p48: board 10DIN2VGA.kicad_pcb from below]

Board: 2 copper layers, 22.4 x 24.1 mm, 12 parts (7 on the bottom side), 20 nets.

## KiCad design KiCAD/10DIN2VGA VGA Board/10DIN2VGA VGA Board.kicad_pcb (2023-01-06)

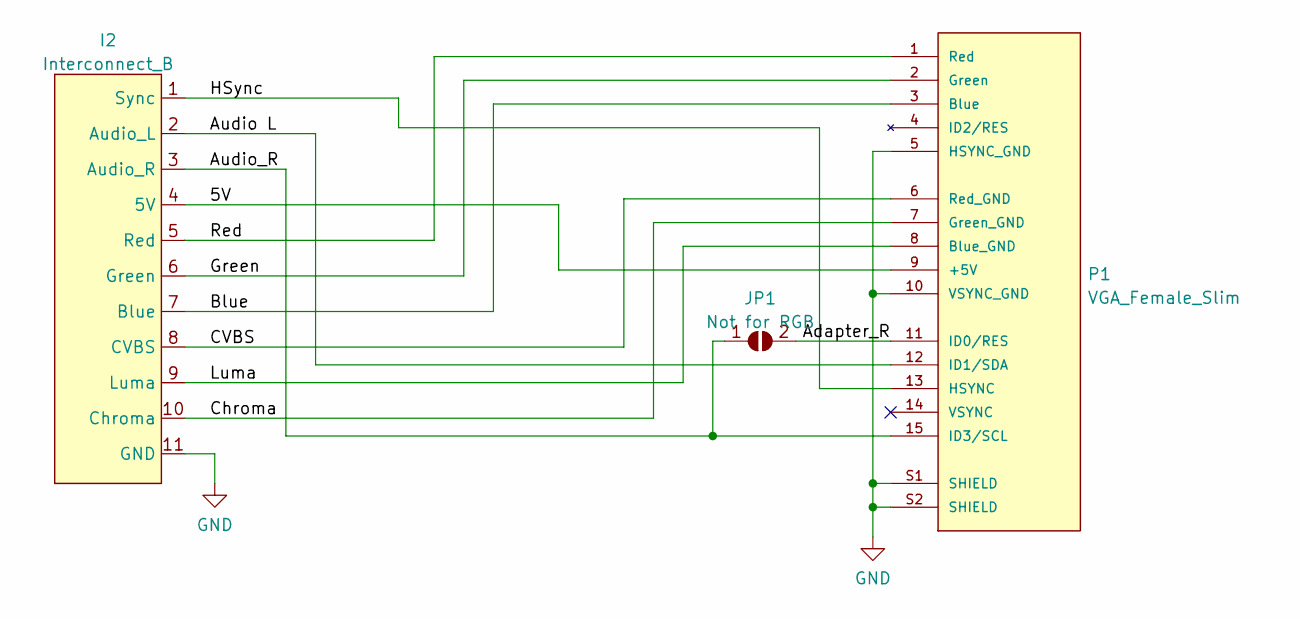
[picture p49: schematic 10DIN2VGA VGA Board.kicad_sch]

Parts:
I2: Interconnect_B
JP1: Not for RGB; SolderJumper-2_P1.3mm_Open_RoundedPad1.0x1.5mm
P1: VGA_Female_Slim; VGA_female_rightangle_slim; PARTREV N/A

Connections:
/5V: I2.4 (5V), P1.9 (+5V)
/Adapter_R: JP1.2 (B), P1.11 (ID0/RES)
/Audio L: I2.2 (Audio_L), P1.12 (ID1/SDA)
/Audio_R: I2.3 (Audio_R), JP1.1 (A), P1.15 (ID3/SCL)
/Blue: I2.7 (Blue), P1.3 (Blue)
/CVBS: I2.8 (CVBS), P1.6 (Red_GND)
/Chroma: I2.10 (Chroma), P1.7 (Green_GND)
/Green: I2.6 (Green), P1.2 (Green)
/HSync: I2.1 (Sync), P1.13 (HSYNC)
/Luma: I2.9 (Luma), P1.8 (Blue_GND)
/Red: I2.5 (Red), P1.1 (Red)
GND: I2.11 (GND), P1.5 (HSYNC_GND), P1.10 (VSYNC_GND), P1.S1 (SHIELD), P1.S2 (SHIELD)

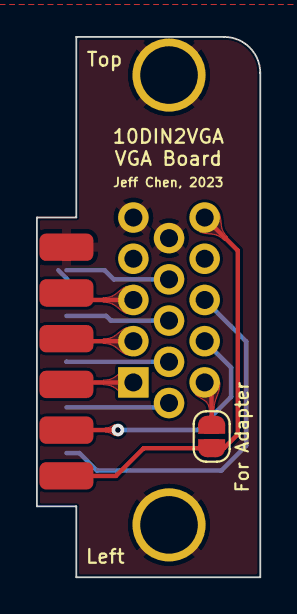
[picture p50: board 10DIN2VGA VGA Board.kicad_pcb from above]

Board: 2 copper layers, 12.4 x 30.0 mm, 3 parts (1 on the bottom side), 12 nets.

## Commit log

2023-01-06 更新 README.md
2023-01-07 Update Back Shell Design
    [Shell Back-RGB.stl, Shell Back-YC.stl, Shell Back.stl]

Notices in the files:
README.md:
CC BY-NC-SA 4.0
